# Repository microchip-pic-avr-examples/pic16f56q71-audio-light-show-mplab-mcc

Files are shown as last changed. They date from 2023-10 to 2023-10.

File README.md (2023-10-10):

MCHP (https://www.microchip.com)

# Audio Light Show Using PIC18-Q71

This project shows the functionality behind a real-time audio processing light show built extremely efficiently on a PIC18-Q71 microcontroller (MCU). 90% of the functionality runs on the MCU without engaging the CPU through the use of various Core-Independent Peripherals (CIPs).

The PIC18-Q71 on-chip analog, consisting of the Operational Amplifier ([OPA](https://www.microchip.com/en-us/products/microcontrollers-and-microprocessors/8-bit-mcus/core-independent-and-analog-peripherals/integrated-analog/operational-amplif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)) and Analog-to-Digital Converter ([ADC](https://www.microchip.com/en-us/products/microcontrollers-and-microprocessors/8-bit-mcus/core-independent-and-analog-peripherals/integrated-analog/analog-to-digital-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)) modules, measure the incoming analog frequencies and use Direct Memory Access ([DMA](https://www.microchip.com/en-us/products/microcontrollers-and-microprocessors/8-bit-mcus/core-independent-and-analog-peripherals/system-flexibility/direct-memory-acc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)) to transfer the readings into the Universal Asynchronous Receiver and Transmitter ([UART](https://www.microchip.com/en-us/products/microcontrollers-and-microprocessors/8-bit-mcus/core-independent-and-analog-peripherals/communication-connectivity-periphera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))/[DMX512](https://www.microchip.com/en-us/products/microcontrollers-and-microprocessors/8-bit-mcus/core-independent-and-analog-peripherals/communication-connectivity-periphera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) module to transmit to the receivers. Each receiver also uses a PIC18-Q71 to receive the DMX data and then appropriately drives WS2812 LEDs through its Serial Peripherals Interface ([SPI](https://www.microchip.com/en-us/products/microcontrollers-and-microprocessors/8-bit-mcus/core-independent-and-analog-peripherals/communication-connectivity-periphera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)) module. The receivers are daisy-chained through ethernet cables that transfer both data and power.

The first image below displays seven receviers responding to music, while the other one shows a standby effect. The transmitter has an AUX cable plugged in off-screen.

DMX Video 2
DMX Video 1

## Related Documentation

- [PIC18-Q71 Data Sheet](https://ww1.microchip.com/downloads/aemDocuments/documents/MCU08/ProductDocuments/DataSheets/PIC18F26-46-56Q71-Microcontroller-Data-Sheet-DS40002329.pdf)
- [TB3204 - DMX-512 using the UART with Protocol Support](https://ww1.microchip.com/downloads/en/Appnotes/TB3204-DMX-512-using-UART-90003204A.pdf) - Setting up DMX with DMA on a PIC18
- [PIC18F56Q71 Curiosity Nano Hardware User Guide](https://ww1.microchip.com/downloads/aemDocuments/documents/MCU08/ProductDocuments/UserGuides/PIC18F56Q71-CuriosityNano-HW-UG-DS50003481.pdf) - Development tools documentation
- [MIC28517 Data Sheet](https://ww1.microchip.com/downloads/aemDocuments/documents/APID/ProductDocuments/DataSheets/MIC28517-Data-Sheet-DS20006317C.pdf) - Voltage Converter Data Sheet 

## Software Used

- [MPLAB® X IDE 6.1.5](https://www.microchip.com/en-us/development-tools-tools-and-software/mplab-x-ide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) or newer
- [MPLAB XC8 2.45.0](https://www.microchip.com/en-us/development-tools-tools-and-software/mplab-xc-compilers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) or newer
- [MPLAB Code Configurator (MCC) 3.95.0](https://www.microchip.com/mplab/mplab-code-configurator) or newer

## Setup

To operate the demo, connect all the transmitters and receivers with an Ethernet cable. Power up the transmitter with a 48V power supply and connect an AUX cable to watch the incoming audio signal come to life. Each receiver is selectively listening to specific DMX data. A DIP switch on each receiver dictates what incoming DMX data to listen to, effectively defining a node number.

Apart from the final transmitter and receiver boards shown in the initial image representations, 3D printed stands are also shown which are used to mount the receiver boards and the diffusing tubes. The diffusing tubes consist of WS2812 LEDs taped to an aluminum strip for support. Inside the fluorescent tube guard, parchment paper lines the interiors and a 3D printed cap securely holds the aluminum strip towards the back of the tube ensuring optimal LED diffusion.

## Theory of Operation

This demo can be broken up into three portions:
* [Audio Signal Processing](#audio-signal-processing)
* [DMX Data](#dmx-data)
* [Driving the WS2812 LEDs](#driving-the-ws2812-leds)

The distinguishing feature of this project is nearly all of this demo operates without the CPU, and instead using CIPs and the DMA. The CPU's sole task is to run the manually programmed visual effects that convert the acquired frequency data into LED data.

### Audio Signal Processing
To obtain the initial audio data, this project extracts bins of audio frequencies and performs peak detection on each bin giving a value corresponding to the intensity of the audio frequency. Each peak is then visually represented on a different LED tube.

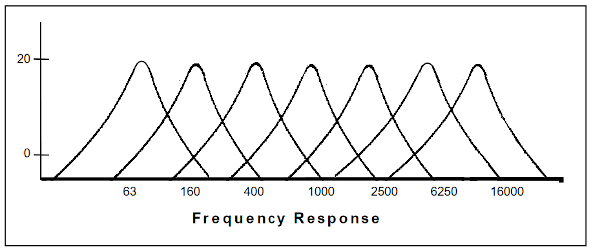
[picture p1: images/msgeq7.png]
Frequency peaks


Source: [MSGEQ7 data sheet](https://www.sparkfun.com/datasheets/Components/General/MSGEQ7.pdf)

To extract and acquire these audio frequency bins, analog bandpass filters with an ADC can be used for each desired frequency. Alternatively, an MSGEQ7 chip was used to reduce the number of needed passive components. This chip functions as a bandpass filter, multiplexing between frequencies. The PIC18-Q71 drives the chip to change where the center frequency is and then uses its on-board ADC to sample the peak. The PIC18-Q71's OPA is used in Unity Gain mode to impedance match the output, then the ADC with computation is used to acquire the output peak.

By using the OPA in Unity Gain mode, a buffer is created that ensures the ADC can read the analog signal without affecting it. If the input from the filters is of high impedance, the ADC may not read the result accurately. By using the OPA as a buffer, this ensures the ADC can always read the signal accurately and without affecting the original signal. Also, the ADC has built-in computation that provides an automatic average of readings to eliminate potential outliers, providing a more accurate reading.

### DMX Data
DMX512, or DMX for short, is an industry-standard protocol commonly used to control stage lighting and theatrical effects, providing centralized control of multiple devices from a single controller. Devices in a DMX network are daisy-chained together creating a "DMX universe". Within each universe, each node listens to the start code and specific data bytes out of the 512 bytes in each packet.

DMX Universe

For this DMX light show, each node listens to 3 bytes and the start code. Depending on the start code, the nodes interpret their three bytes differently, giving DMX flexibility on the fly.

DMX Reactive

| Start Code | Mode | Byte 1 | Byte 2 | Byte 3 |
| ---- | ---- | ---- | ---- | ---- |
| 2 | Reactive | G LED Data  | R LED Data | B LED Data |
| 3 | Visualizer | # of LEDs to Turn On | Color Change Threshold 1 | Color Change Threshold 2 |

 When `Start Code = 2`, each byte represents the entire tube's RGB data. For the first receiver, when `Start Code = 2` and the data are as shown above (`G = 255, R = 0, B = 0`), the tube looks like in the left image. When `Start Code = 3`, the data interpretation is altered to the table below and the tube for receiver 1 changes to what is shown in the image on the right.
 
DMX Visualizer

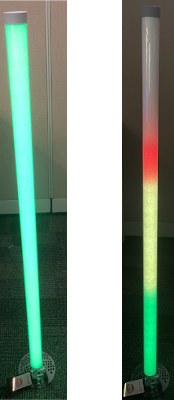
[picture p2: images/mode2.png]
Tube Shown Reactive


DMX provides the needed structure for fast and flexible data. The PIC18-Q71 compliments DMX by allowing the data's meaning to be changed based on Input/Output (I/O). The data interpretation is changed by toggling a switch, which changes the start code.

### Driving the WS2812 LEDs
After the DMX data has been received, the WS2812 LEDs change to reflect the incoming data. WS2812 LEDs are programmable through a 1-Wire protocol. The LEDs are daisy-chained together, similar to the DMX protocol, but each LED receives all the data, strips off its portion, and sends the data onward. The data for each LED consists of one byte for G, R, and B data respectively (for a total of three bytes).

WS2812

To drive the WS2812 protocol, the microcontroller pulls a line high or low for different amounts of time:

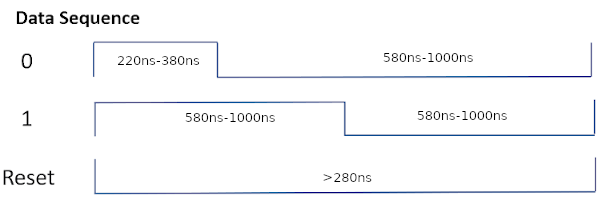
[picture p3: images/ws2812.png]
WS2812 Timing


This requires an I/O line to be changed every 220 ns or at least 4.5 million times per second requiring 4.5 Mhz of processing power. This could create a processing bottleneck in time-sensitive applications. Alternatively, the SPI module of the PIC18-Q71 device family can creatively drive the WS2812 protocol in hardware, so that the MCU simply needs to load the SPI buffer with multiple data bytes instead of individually driving each bit. This is done by chaining the SPI module with the PWM and Configurable Logic Cell (CLC) CIPs to create the serial output needed by the WS2812 protocol.

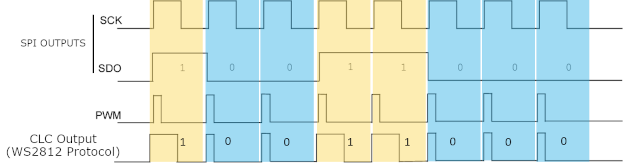
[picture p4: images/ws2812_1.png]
WS2812 1 Implementation


*SPI + PWM + CLC Waveform*

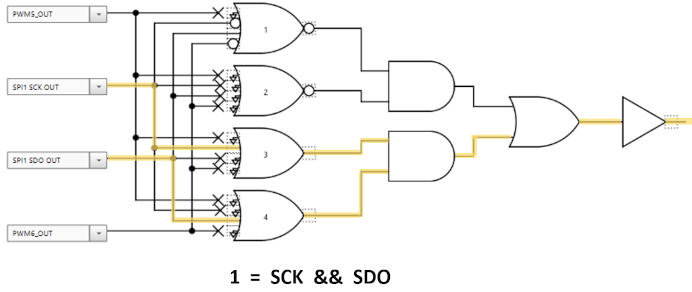
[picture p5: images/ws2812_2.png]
WS2812 2 Implementation


Implementation with CLC's - Generating 0's

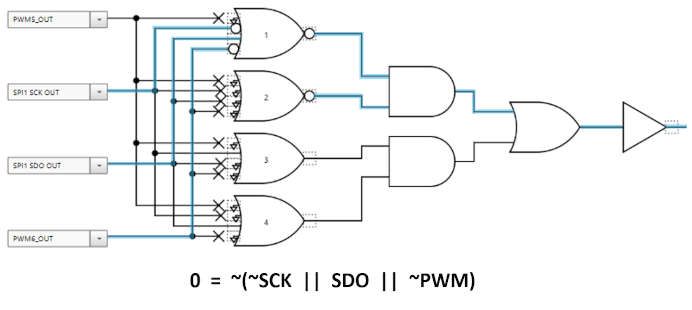
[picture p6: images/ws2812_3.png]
WS2812 3 Implementation


Implementation with CLC's - Generating 1's

## Development Hardware Used

For a large-scale project that shows many moving parts working together, it helps to first set up using easy-to-use hardware, then transition to something more polished and stable.

This project was first set up using [Curiosity Development boards](https://www.microchip.com/en-us/tools-resources/evaluation-boards/curiosity) and jumper wires. Curiosity Development boards feature an on-board programmer, meaning that only a USB cable was needed to program each PIC18-Q71. As the features were developed and the hardware requirements stopped changing, the project was transitioned to dedicated PCBs. Below is the main hardware used for the initial prototype.

- PIC18F56Q71 Curiosity Nano ([EV01G21A](https://www.microchip.com/en-us/development-tool/EV01G21A))
- Curiosity Nano Base for Click Boards™ ([AC164162](https://www.microchip.com/en-us/development-tool/ac164162))
- [MSGEQ7 Graphic Equalizer Display Filter](https://www.sparkfun.com/products/10468)
- [WS2812 LED Strip](https://www.amazon.com/BTF-LIGHTING-Waterproof-Flexible-Individually-Addressable/dp/B01CDTEEZ2/)

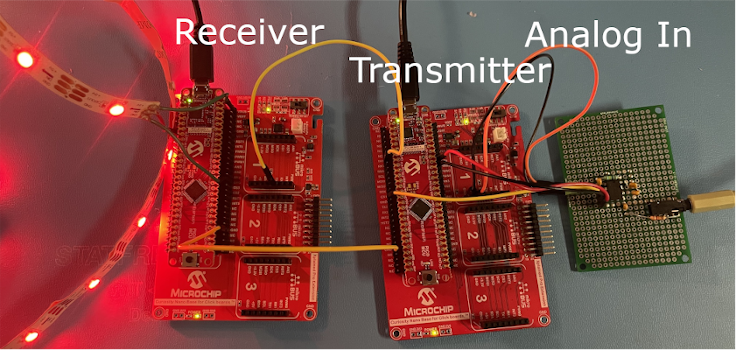
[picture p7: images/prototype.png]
Prototype Hardware


The perfboard held the supporting circuitry for the MSGEQ7 to acquire the analog signal. After the analog signal was acquired, a single-ended signal transmitted the DMX data to the receiver board which drive the WS2812 LED, as shown on the left. One other notable point is the Curiosity Nanos all needed to connect to A/C power, greatly limiting the decentralized nature of the daisy-chained DMX protocol. The PIC18F56Q71 was used since it is the family variation used on the Curiosity Nano boards, but any PIC18-Q71 can be used for the project, provided the pin output settings were changed in the code.

The final design was built on PCBs that encoded the DMX signal per the DMX specification, using RS-485 differential signaling for signal integrity of up to 4,000 feet. Also, instead of using XLR cables for the DMX signal, Ethernet cables were used, enabling Power over Ethernet (PoE) to be run through the same cable, eliminating the central power source requirement. This allows only one connection to a power source and large cable runs for the demo to be set up across a stage or even a room - perfect for traveling musicians who need to set up and tear down their equipment quickly.

## Final Hardware Used

- [MPLAB PICkit™ 5 In-Circuit Debugger](https://www.microchip.com/en-us/development-tool/pg164150)

### The Transmitter
The transmitter was built on a custom 4-layer PCB. All parts used are in the [Transmitter Bill of Materials](./PCBs/DMX%20Transmitter/dmxTxBOM.csv) in this repository, as well as all of the corresponding [files needed to have the boards manufactured](./PCBs/DMX%20Transmitter/dmxTx-Outputs.zip). Similar to the prototype hardware, the audio signal comes in and the PIC18-Q71 processes it and sends out the DMX data, but this time, it does so on an Ethernet cable. As noted above, passive PoE was implemented so a 48V power source is used and a MIC28517 buck converter steps down the voltage to the MCU's required five volts.

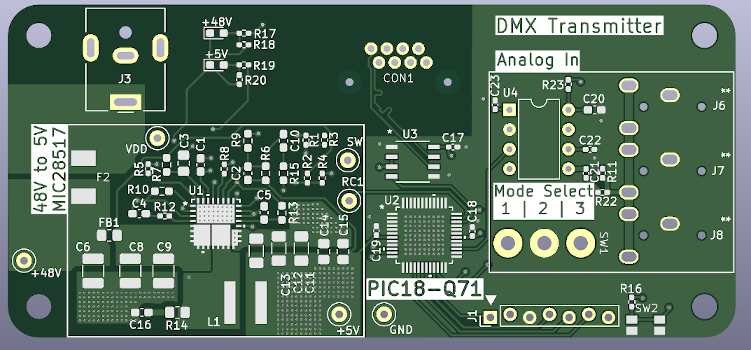
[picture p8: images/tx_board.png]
TX Board Unpopulated


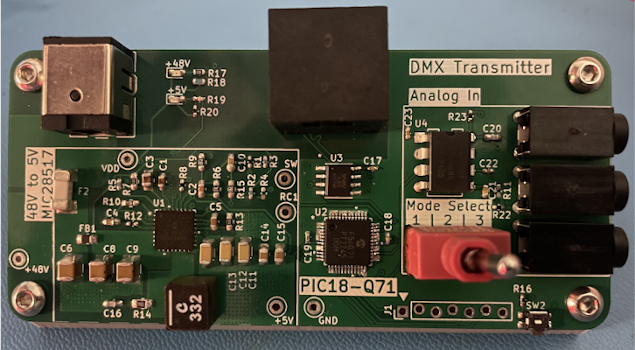
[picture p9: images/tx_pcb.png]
TX Board Populated


Notable parts in each of the section of the board:

## Analog In
 The [MSGEQ7](https://www.sparkfun.com/products/10468) extracts the amplitudes of seven frequency bands from an audio signal to be displayed.

## PIC18-Q71
The [PIC18-Q71](https://www.microchip.com/en-us/products/microcontrollers-and-microprocessors/8-bit-mcus/pic-mcus/pic18-q71) drives and reads the MSGEQ7 output by first matching the analog impedance using its on-chip OPA as a unity gain buffer, then sampling the signal using its ADC. It then sends out lighting data to each of the receiver nodes over DMX.

## 48 to 5V
The [MIC28517](https://www.microchip.com/en-us/product/mic28517) was chosen since it can handle the 48V requirements of PoE while providing up to 8A. Each receiver node needs up to 1.5A for the WS2812 LEDs, so this chip gives us plenty of overhead.

## SP485
This chip converts the outgoing DMX signal into a differential pair (RS-485) for increased signal distance (U3 on schematic).

### The Receivers
The receiver [Bill of Materials](./PCBs/DMX%20Receiver/dmxRx.csv) and [board files](./PCBs/DMX%20Receiver/dmxRx-v2Outputs.zip) are included in this repository. The receivers function the same as in the prototype, but have Ethernet connectors on either side pass through the power and DMX signals to continue the daisy chain. The PIC18-Q71 on each receiver takes the DMX data in and then appropriately drives the WS2812 LEDs using its CIPs. Each receiver is programmed using a PICkit™ 5 programmer, as opposed to the on-board PKOB programmer on the Curiosity Nanos used during development.

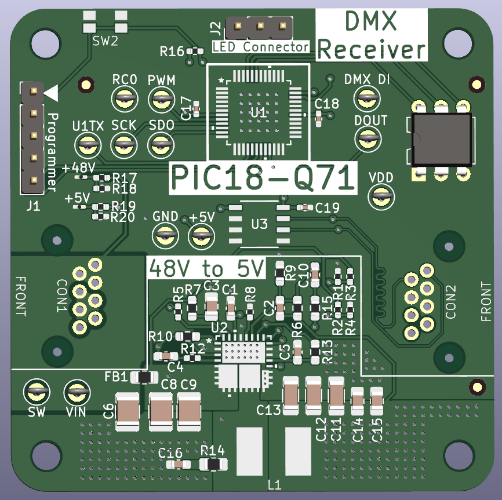
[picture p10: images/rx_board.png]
RX Board Unpopulated

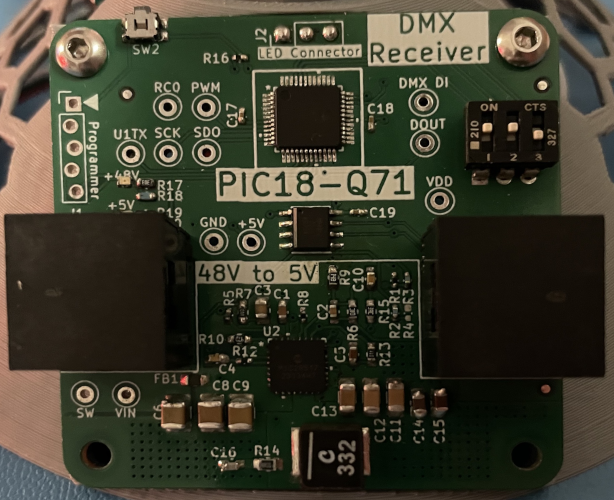
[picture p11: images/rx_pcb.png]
RX Board Populated


## Summary
This project covered the theory and functional implementation of a real-time audio light show using the PIC18-Q71. It provides the foundation for scaling this idea into a full-scale application or modifying it as needed.

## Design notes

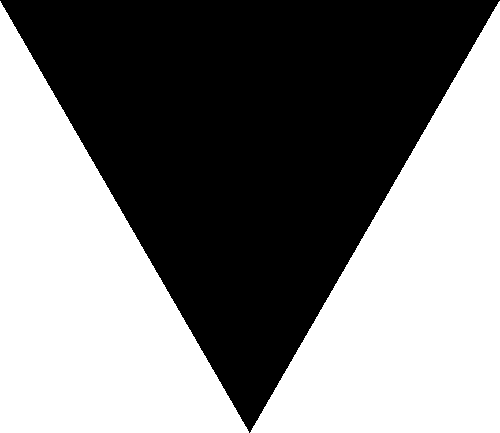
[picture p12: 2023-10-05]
PCB_Design_Files/DMX Receiver/pickit_arrow.png

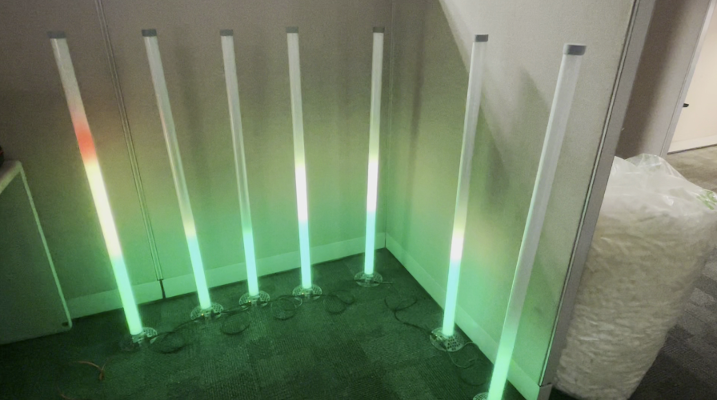
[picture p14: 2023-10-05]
images/demo_functional.png

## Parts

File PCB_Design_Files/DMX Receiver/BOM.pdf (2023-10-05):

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

https://www.digikey.com/en/products/detail/coilcraft/XGL6060-332MEC/15794210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

https://www.digikey.com/en/products/detail/yageo/AC0603FR-1010KL/13694182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

https://www.digikey.com/en/products/detail/panasonic-electronic-components/EVQ-P7A01P/4429447

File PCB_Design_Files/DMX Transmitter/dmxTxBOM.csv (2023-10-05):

Source: | C:\Users\C70636\Git Repo\dmx\PCBs\DMX Transmitter\dmxTx.kicad_sch
Date: | 8/28/2023 8:48:47 AM
Tool: | Eeschema 7.0.6
Generator: | C:\Program Files\KiCad\7.0\bin\scripting\plugins/bom_csv_grouped_by_value_with_fp.py
Component Count: | 69
Ref | Qnty | Value | Cmp name | Footprint | Description | Vendor | DNP
C1, C5 | 2 | 4.7uF | C | Capacitor_SMD:C_0603_1608Metric_Pad1.08x0.95mm_HandSolder | Unpolarized capacitor | https://www.digikey.com/en/products/detail/murata-electronics/GRM188C71A475KE11D/4905309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
C2 | 1 | 4700pF | C | Capacitor_SMD:C_0603_1608Metric_Pad1.08x0.95mm_HandSolder | Unpolarized capacitor | https://www.digikey.com/en/products/detail/kemet/C0603C472K5RACAUTO/3314891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
C3 | 1 | 1uF | C | Capacitor_SMD:C_0805_2012Metric_Pad1.18x1.45mm_HandSolder | Unpolarized capacitor | https://www.digikey.com/en/products/detail/murata-electronics/GCM21BC72A105KE36L/6606065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
C4, C10 | 2 | 0.1uF | C | Capacitor_SMD:C_0603_1608Metric_Pad1.08x0.95mm_HandSolder | Unpolarized capacitor | https://www.digikey.com/en/products/detail/w%C3%BCrth-elektronik/885012206120/11479578
C6, C8, C9 | 3 | 10uF | C | Capacitor_SMD:C_1210_3225Metric_Pad1.33x2.70mm_HandSolder | Unpolarized capacitor | https://www.digikey.com/en/products/detail/murata-electronics/GRM32EC72A106KE05L/7319245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
C11, C12, C13 | 3 | 100uF | C | Capacitor_SMD:C_1206_3216Metric_Pad1.33x1.80mm_HandSolder | Unpolarized capacitor | https://www.digikey.com/en/products/detail/samsung-electro-mechanics/CL31A107MQHNNNE/3889868
C14, C15 | 2 | 22uF | C | Capacitor_SMD:C_0805_2012Metric_Pad1.18x1.45mm_HandSolder | Unpolarized capacitor | https://www.digikey.com/en/products/detail/murata-electronics/GRM21BC81C226ME44L/4905510
C16 | 1 | 1000pF | C | Capacitor_SMD:C_0603_1608Metric_Pad1.08x0.95mm_HandSolder | Unpolarized capacitor | https://www.digikey.com/en/products/detail/w%C3%BCrth-elektronik/885012206120/11479578
C17, C18, C19, C22, C23 | 5 | 0.1u | C | Capacitor_SMD:C_0402_1005Metric_Pad0.74x0.62mm_HandSolder | Unpolarized capacitor | https://www.digikey.com/en/products/detail/samsung-electro-mechanics/CL05A104KA5NNNC/3886701
C20 | 1 | 33p | C | Capacitor_SMD:C_0603_1608Metric_Pad1.08x0.95mm_HandSolder | Unpolarized capacitor | https://www.digikey.com/en/products/detail/kemet/C0603C330K4HAC7867/7946792
C21 | 1 | 0.01u | C | Capacitor_SMD:C_0402_1005Metric_Pad0.74x0.62mm_HandSolder | Unpolarized capacitor | https://www.digikey.com/en/products/detail/samsung-electro-mechanics/CL05B103KB5NNNC/3886686
CON1 | 1 | ~ | E5J88-00LJG2-L | E5J88-00LJG2-L:E5J88-00LJG2-L |  | https://www.digikey.com/en/products/detail/pulse-electronics/E5J88-00LJG2-L/1785312
D1 | 1 | +48V | LED | LED_SMD:LED_0603_1608Metric_Pad1.05x0.95mm_HandSolder | Light emitting diode | https://www.digikey.com/en/products/detail/liteon/LTST-C191KSKT/386839
D2 | 1 | +5V | LED | LED_SMD:LED_0603_1608Metric_Pad1.05x0.95mm_HandSolder | Light emitting diode | https://www.digikey.com/en/products/detail/liteon/LTST-C190GKT/269230
F1 | 1 | High Amp | Fuse | 0679L9100-05:0679L9100-05 | Fuse | https://www.digikey.com/en/products/detail/bel-fuse-inc/0679L9100-05/5844042
F2 | 1 | Low Amp | Fuse | 0679L9100-05:0679L9100-05 | Fuse | https://www.digikey.com/en/products/detail/bel-fuse-inc/0679L1000-05/5844030
FB1 | 1 | 120R | FerriteBead | Resistor_SMD:R_0805_2012Metric_Pad1.20x1.40mm_HandSolder | Ferrite bead | https://www.digikey.com/en/products/detail/vishay-dale/ILHB0805ER121V/5168396
H1, H2, H3, H4 | 4 | MountingHole | MountingHole | MountingHole:MountingHole_3.2mm_M3 | Mounting Hole without connection | N/A
J1 | 1 | Conn_01x07_Socket | Conn_01x07_Socket | Connector_PinHeader_2.54mm:PinHeader_1x07_P2.54mm_Vertical | Generic connector, single row, 01x07, script generated | https://www.digikey.com/en/products/detail/adam-tech/PH1-07-UA/9830505
J3 | 1 | Jack-DC | Jack-DC | PJ-063AH:BarrelJack_CUI_PJ-063AH_Horizontal | DC Barrel Jack | https://www.digikey.com/en/products/detail/cui-devices/PJ-063AH/2161208?s=N4IgTCBcDaIAoCkC0AGAbAZgIIAkQF0BfIA
J6, J7, J8 | 3 | STX-3000 | STX-3000 | STX-3000_KYC |  | https://www.digikey.com/en/products/detail/kycon-inc/STX-3000/9975995?s=N4IgTCBcDaIMoBUAaBaAzABiyAugXyA
L1 | 1 | 3.3uH | L | XGL6060:XGL6060 | Inductor | https://www.digikey.com/en/products/detail/coilcraft/XGL6060-332MEC/15794210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
R1 | 1 | 300k | R | Resistor_SMD:R_0402_1005Metric_Pad0.72x0.64mm_HandSolder | Resistor | https://www.digikey.com/en/products/detail/panasonic-electronic-components/ERJ-2RKF3003X/1746185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
R2, R3, R5 | 3 | 100k | R | Resistor_SMD:R_0402_1005Metric_Pad0.72x0.64mm_HandSolder | Resistor | https://www.digikey.com/en/products/detail/koa-speer-electronics-inc/RK73H1ETTP1003F/9844156
R4 | 1 | 0R | R | Resistor_SMD:R_0402_1005Metric_Pad0.72x0.64mm_HandSolder | Resistor | https://www.digikey.com/en/products/detail/koa-speer-electronics-inc/RK73H1ETTP1003F/9844156 | DNP
R6 | 1 | 10k | R | Resistor_SMD:R_0603_1608Metric_Pad0.98x0.95mm_HandSolder | Resistor | https://www.digikey.com/en/products/detail/yageo/AC0603FR-1010KL/13694182
R7, R13 | 2 | 1R | R | Resistor_SMD:R_0603_1608Metric_Pad0.98x0.95mm_HandSolder | Resistor | https://www.digikey.com/en/products/detail/stackpole-electronics-inc/RNCP0603FTD1R00/2240072
R8, R12 | 2 | 0R | R | Resistor_SMD:R_0402_1005Metric_Pad0.72x0.64mm_HandSolder | Resistor | https://www.digikey.com/en/products/detail/panasonic-electronic-components/ERJ-2GE0R00X/146727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
R9 | 1 | 1.37k | R | Resistor_SMD:R_0603_1608Metric_Pad0.98x0.95mm_HandSolder | Resistor | https://www.digikey.com/en/products/detail/yageo/RC0603FR-071K37L/726860
R10 | 1 | 3.01k | R | Resistor_SMD:R_0603_1608Metric_Pad0.98x0.95mm_HandSolder | Resistor | https://www.digikey.com/en/products/detail/yageo/RC0603FR-073K01L/727121
R14 | 1 | 1R | R | Resistor_SMD:R_0805_2012Metric_Pad1.20x1.40mm_HandSolder | Resistor | https://www.digikey.com/en/products/detail/stackpole-electronics-inc/RMCF0805FT1R00/1760547
R15 | 1 | 24.9k | R | Resistor_SMD:R_0603_1608Metric_Pad0.98x0.95mm_HandSolder | Resistor | https://www.digikey.com/en/products/detail/yageo/RC0603FR-0724K9L/727080
R16 | 1 | 10k | R | Resistor_SMD:R_0402_1005Metric_Pad0.72x0.64mm_HandSolder | Resistor | https://www.digikey.com/en/products/detail/yageo/AC0402FR-0710KL/5895030
R17, R19 | 2 | 1k | R | Resistor_SMD:R_0402_1005Metric_Pad0.72x0.64mm_HandSolder | Resistor | https://www.digikey.com/en/products/detail/susumu/RR0510P-102-D/432398
R18 | 1 | 47 | R | Resistor_SMD:R_0402_1005Metric_Pad0.72x0.64mm_HandSolder | Resistor | https://www.digikey.com/en/products/detail/yageo/RC0402FR-0747RL/2827566
R20 | 1 | 790 | R | Resistor_SMD:R_0402_1005Metric_Pad0.72x0.64mm_HandSolder | Resistor | https://www.digikey.com/en/products/detail/yageo/RC0402FR-07787RL/5281093
R22 | 1 | 22k | R | Resistor_SMD:R_0402_1005Metric_Pad0.72x0.64mm_HandSolder | Resistor | https://www.digikey.com/en/products/detail/panasonic-electronic-components/ERA-2AEB223X/1706037
R23 | 1 | 200k | R | Resistor_SMD:R_0402_1005Metric_Pad0.72x0.64mm_HandSolder | Resistor | https://www.digikey.com/en/products/detail/yageo/RT0402BRD07200KL/5926115
SW1 | 1 | SW_SPDT_MSM | SW_SPDT_MSM | 100AWDP1T2B4M2QE:100AWDP1T2B4M2QE | Switch, single pole double throw, center OFF position | https://www.digikey.com/en/products/detail/e-switch/100AWSP1T2B4M2QE/1803039
SW2 | 1 | MCLR_SW | SW_Push | EVQ-P7A01P:EVQ-P7A01P | Push button switch, generic, two pins | https://www.digikey.com/en/products/detail/panasonic-electronic-components/EVQ-P7A01P/4429447
TP3 | 1 | RC1 | TestPoint | TestPoint:TestPoint_Loop_D2.50mm_Drill1.0mm | test point | N/A
TP5 | 1 | +48V | TestPoint | TestPoint:TestPoint_Loop_D2.50mm_Drill1.0mm | test point | N/A
TP9 | 1 | +5V | TestPoint | TestPoint:TestPoint_Loop_D2.50mm_Drill1.0mm | test point | N/A
TP10 | 1 | GND | TestPoint | TestPoint:TestPoint_Loop_D2.50mm_Drill1.0mm | test point | N/A
U1 | 1 | MIC28517T-E/PHA | MIC28517T-E_PHA | VQFN32_6X6_3EP_PHA_MCH |  | https://www.microchip.com/en-us/product/mic28517
U2 | 1 | PIC18F56Q71-I/PT | PIC18F56Q71-I_PT | TQFP48_PT_MCH |  | https://www.digikey.com/en/products/detail/microchip-technology/PIC18F56Q71-I-PT/17631044
U3 | 1 | SP485CN-L | SP485CN-L | NSOIC-8 |  | https://www.digikey.com/en/products/detail/maxlinear-inc/SP485CN-L/2411099
U4 | 1 | MSGEQ7 | MSGEQ7 | Package_DIP:DIP-8_W7.62mm | Seven Band Graphic Equalizer, DIP-8/SOIC-8 | https://www.sparkfun.com/products/10468

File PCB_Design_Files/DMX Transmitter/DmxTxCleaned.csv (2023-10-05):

Id | Designator | Footprint | Quantity | Designation | Supplier and ref | Column1 | _1
1 | C13,C11,C8,C10 | R_1206_3216Metric | 4 | 2.2uF | https://www.digikey.com/en/products/detail/samsung-electro-mechanics/CL31B225KCHSNNE/3888796
2 | J7,J6,J8 | STX-3000_KYC | 3 | STX-3000 | https://www.digikey.com/en/products/detail/kycon-inc/STX-3000/9975995?s=N4IgTCBcDaIMoBUAaBaAzABiyAugXyA
3 | C3 | R_0603_1608Metric | 1 | 4.7n | https://www.digikey.com/en/products/detail/tdk-corporation/CGA3E2C0G1H472J080AA/2672805
4 | L1 | 7447709006 | 1 | 6.8u | https://www.digikey.com/en/products/detail/w%C3%BCrth-elektronik/7447709006/1638645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
5 | H4,H3,H1,H2 | MountingHole_3.2mm_M3 | 4 | MountingHole | N/A
6 | U1 | VQFN32_6X6_3EP_PHA_MCH | 1 | MIC28517T-E/PHA | https://www.microchip.com/en-us/product/mic28517
7 | R9,R7 | R_0402_1005Metric | 2 | 10k | https://www.digikey.com/en/products/detail/yageo/AC0402FR-0710KL/5895030
8 | C1,C2 | R_0402_1005Metric | 2 | 0.1uF | https://www.digikey.com/en/products/detail/murata-electronics/GRM155R62A104KE14D/5027543
9 | C15,C16 | C_0402_1005Metric | 2 | 0.1u | https://www.digikey.com/en/products/detail/murata-electronics/GRM155R62A104KE14D/5027543
10 | R15 | R_0402_1005Metric | 1 | 790 | https://www.digikey.com/en/products/detail/yageo/RC0402FR-07787RL/5281093
11 | C5,C6 | R_0402_1005Metric | 2 | 47u | https://www.digikey.com/en/products/detail/murata-electronics/GRM21BR61A476ME15K/4905528
12 | U4 | DIP-8_W7.62mm | 1 | MSGEQ7 | https://www.sparkfun.com/products/10468
13 | C7,C14,C4 | R_0402_1005Metric | 3 | .1uF | https://www.digikey.com/en/products/detail/samsung-electro-mechanics/CL05B104KA5NNNC/5961204
14 | D2 | LED_0603_1608Metric | 1 | +5V | N/A
15 | R4 | R_0402_1005Metric | 1 | 25k | https://www.digikey.com/en/products/detail/vishay-dale-thin-film/PNM0402E2502BST1/4341871
16 | C12 | R_0805_2012Metric | 1 | 4.7uF | https://www.digikey.com/en/products/detail/tdk-corporation/C2012X5R2A475K125AC/14642033
17 | R10,R11 | R_0402_1005Metric | 2 | 2.2R | https://www.digikey.com/en/products/detail/yageo/RC0402FR-072R2L/1037048
18 | R8 | R_0402_1005Metric | 1 | 1.37k | https://www.digikey.com/en/products/detail/yageo/RC0402FR-071K37L/5280895
19 | R6 | R_0402_1005Metric | 1 | 2.21k | https://www.digikey.com/en/products/detail/yageo/RC0402FR-072K21L/726554
20 | J1 | PinHeader_1x05_P2.54mm_Vertical | 1 | Conn_01x05_Socket | https://www.digikey.com/en/products/detail/w%C3%BCrth-elektronik/61300511121/4846831
21 | B1 | gnd_bridge | 1 | ~ | N/A
22 | C17 | C_0402_1005Metric | 1 | 33p | https://www.digikey.com/en/products/detail/samsung-electro-mechanics/CL05C330JB5NNNC/3886930
23 | R3 | R_0402_1005Metric | 1 | 100k | https://www.digikey.com/en/products/detail/susumu/RR0510P-104-D/432443
24 | R1,R5,R2 | R_0402_1005Metric | 3 | 200k | https://www.digikey.com/en/products/detail/yageo/RT0402BRD07200KL/5926115
25 | SW1 | 100AWDP1T2B4M2QE | 1 | SW_SPDT_MSM | https://www.digikey.com/en/products/detail/e-switch/100AWSP1T2B4M2QE/1803039
26 | J3 | BarrelJack_CUI_PJ-063AH_Horizontal | 1 | Jack-DC | https://www.digikey.com/en/products/detail/cui-devices/PJ-063AH/2161208?s=N4IgTCBcDaIAoCkC0AGAbAZgIIAkQF0BfIA
27 | R13 | R_0402_1005Metric | 1 | 47 | https://www.digikey.com/en/products/detail/yageo/RC0402FR-0747RL/2827566
28 | R16 | R_0402_1005Metric | 1 | 22k | https://www.digikey.com/en/products/detail/panasonic-electronic-components/ERA-2AEB223X/1706037
29 | C18 | C_0402_1005Metric | 1 | 0.01u | https://www.digikey.com/en/products/detail/kyocera-avx/KGM05AR71E103KH/563223
30 | U2 | TQFP48_PT_MCH | 1 | PIC18F56Q71-I/PT | https://www.microchip.com/en-us/product/pic18f56q71
31 | CON1 | E5J88-00LJG2-L | 1 | ~ | https://www.digikey.com/en/products/detail/pulse-electronics/E5J88-00LJG2-L/1785312
32 | R14,R12 | R_0402_1005Metric | 2 | 1k | https://www.digikey.com/en/products/detail/susumu/RR0510P-102-D/432398
33 | D1 | LED_0603_1608Metric | 1 | +48V | https://www.digikey.com/en/products/detail/liteon/LTST-C191KSKT/386839
34 | U3 | NSOIC-8 | 1 | SP485CN-L | https://www.digikey.com/en/products/detail/maxlinear-inc/SP485CN-L/2411099
35 | C9 | R_1206_3216Metric | 1 | 1uF | https://www.digikey.com/en/products/detail/samsung-electro-mechanics/CL31B105KCHSNNE/3888405
36 | TP10 | TestPoint_Pad_D1.0mm | 1 | GND | N/A
37 | F1 | 0679L9100-05 | 1 | Fuse | https://www.digikey.com/en/products/detail/bel-fuse-inc/0679L9100-05/5844042
38 | TP9 | TestPoint_Pad_D1.0mm | 1 | +5V | N/A
39 | TP2 | TestPoint_Pad_D1.0mm | 1 | RB0 | N/A
40 | TP5 | TestPoint_Pad_D1.0mm | 1 | +48V | N/A
41 | TP3 | TestPoint_Pad_D1.0mm | 1 | RC1 | N/A
42 | TP1 | TestPoint_Pad_D1.0mm | 1 | DMX DO | N/A
43 | TP4 | TestPoint_Pad_D1.0mm | 1 | U1TX | N/A
44 | SW2 | EVQ-P7A01P | 1 | MCLR_SW | https://www.digikey.com/en/products/detail/panasonic-electronic-components/EVQ-P7A01P/4429447

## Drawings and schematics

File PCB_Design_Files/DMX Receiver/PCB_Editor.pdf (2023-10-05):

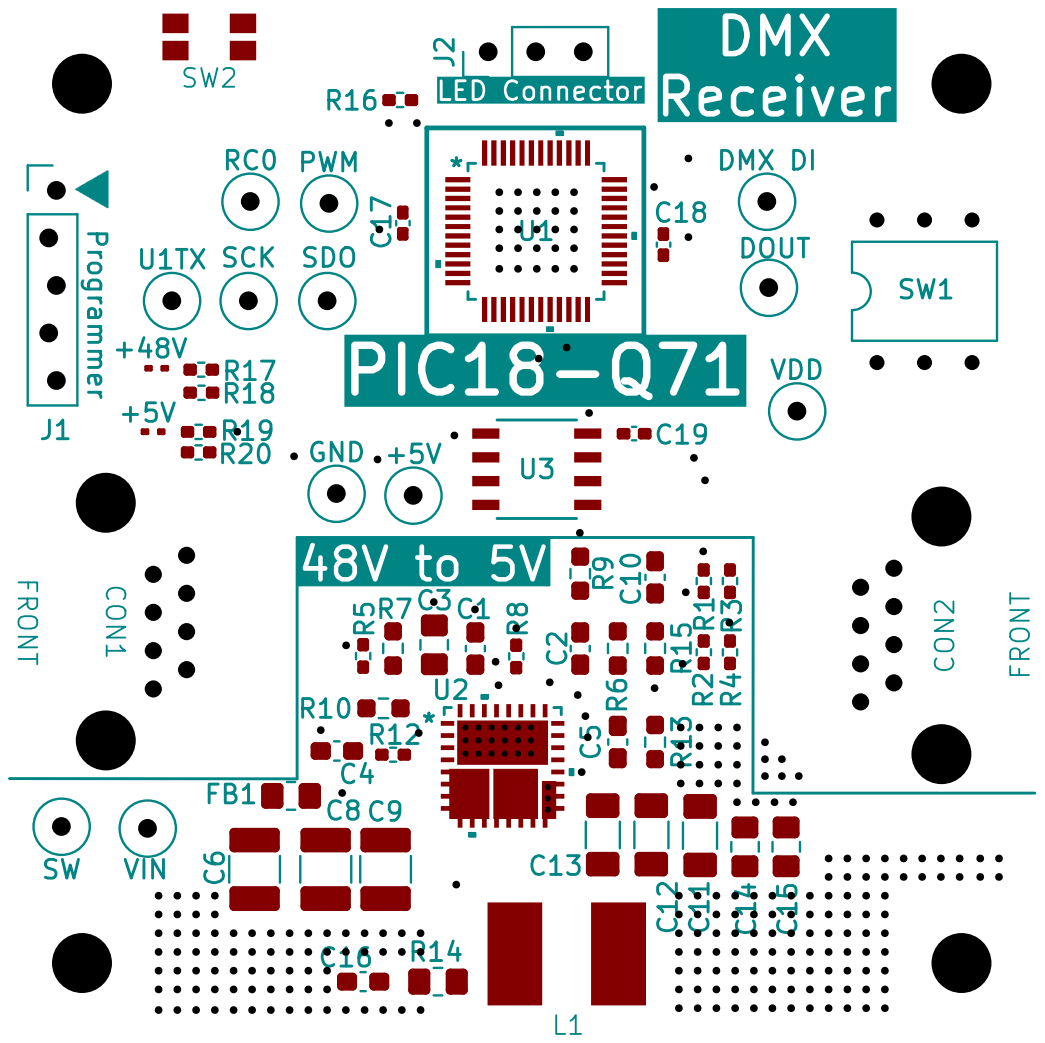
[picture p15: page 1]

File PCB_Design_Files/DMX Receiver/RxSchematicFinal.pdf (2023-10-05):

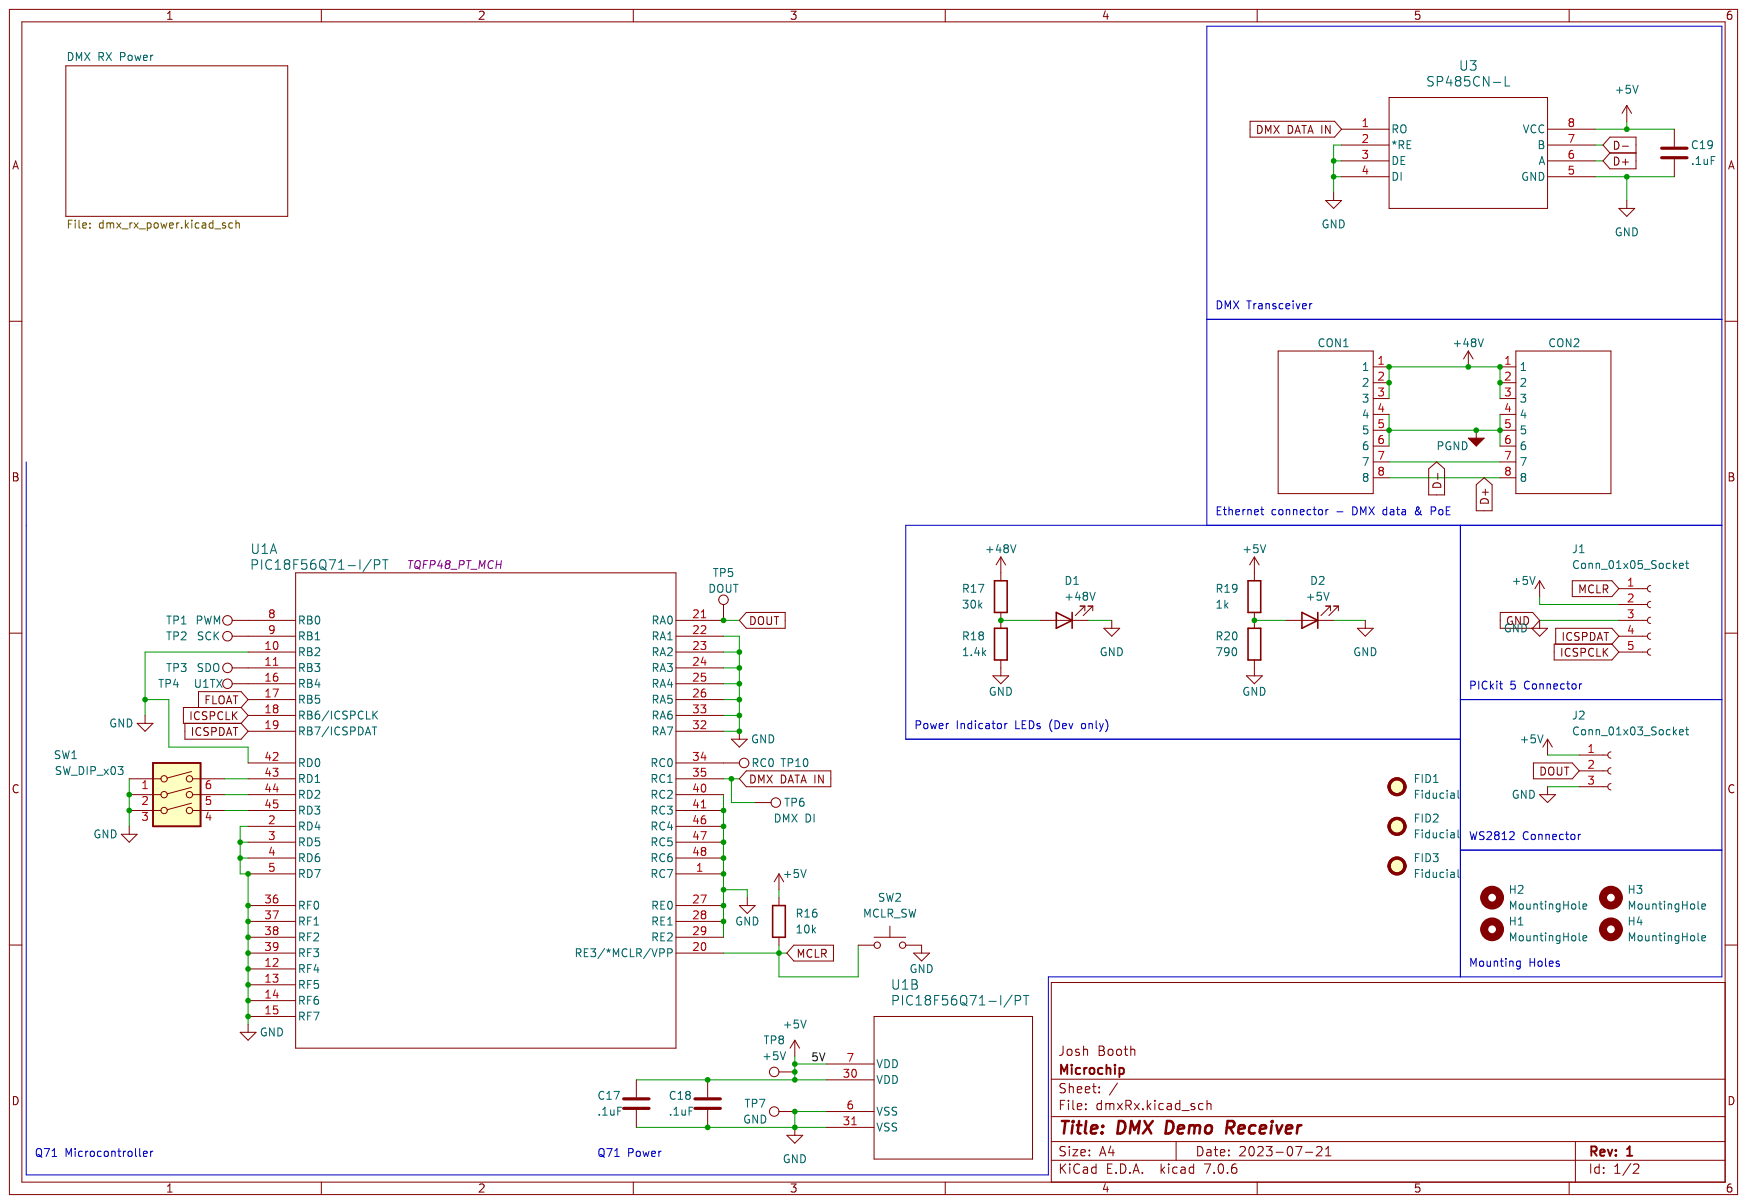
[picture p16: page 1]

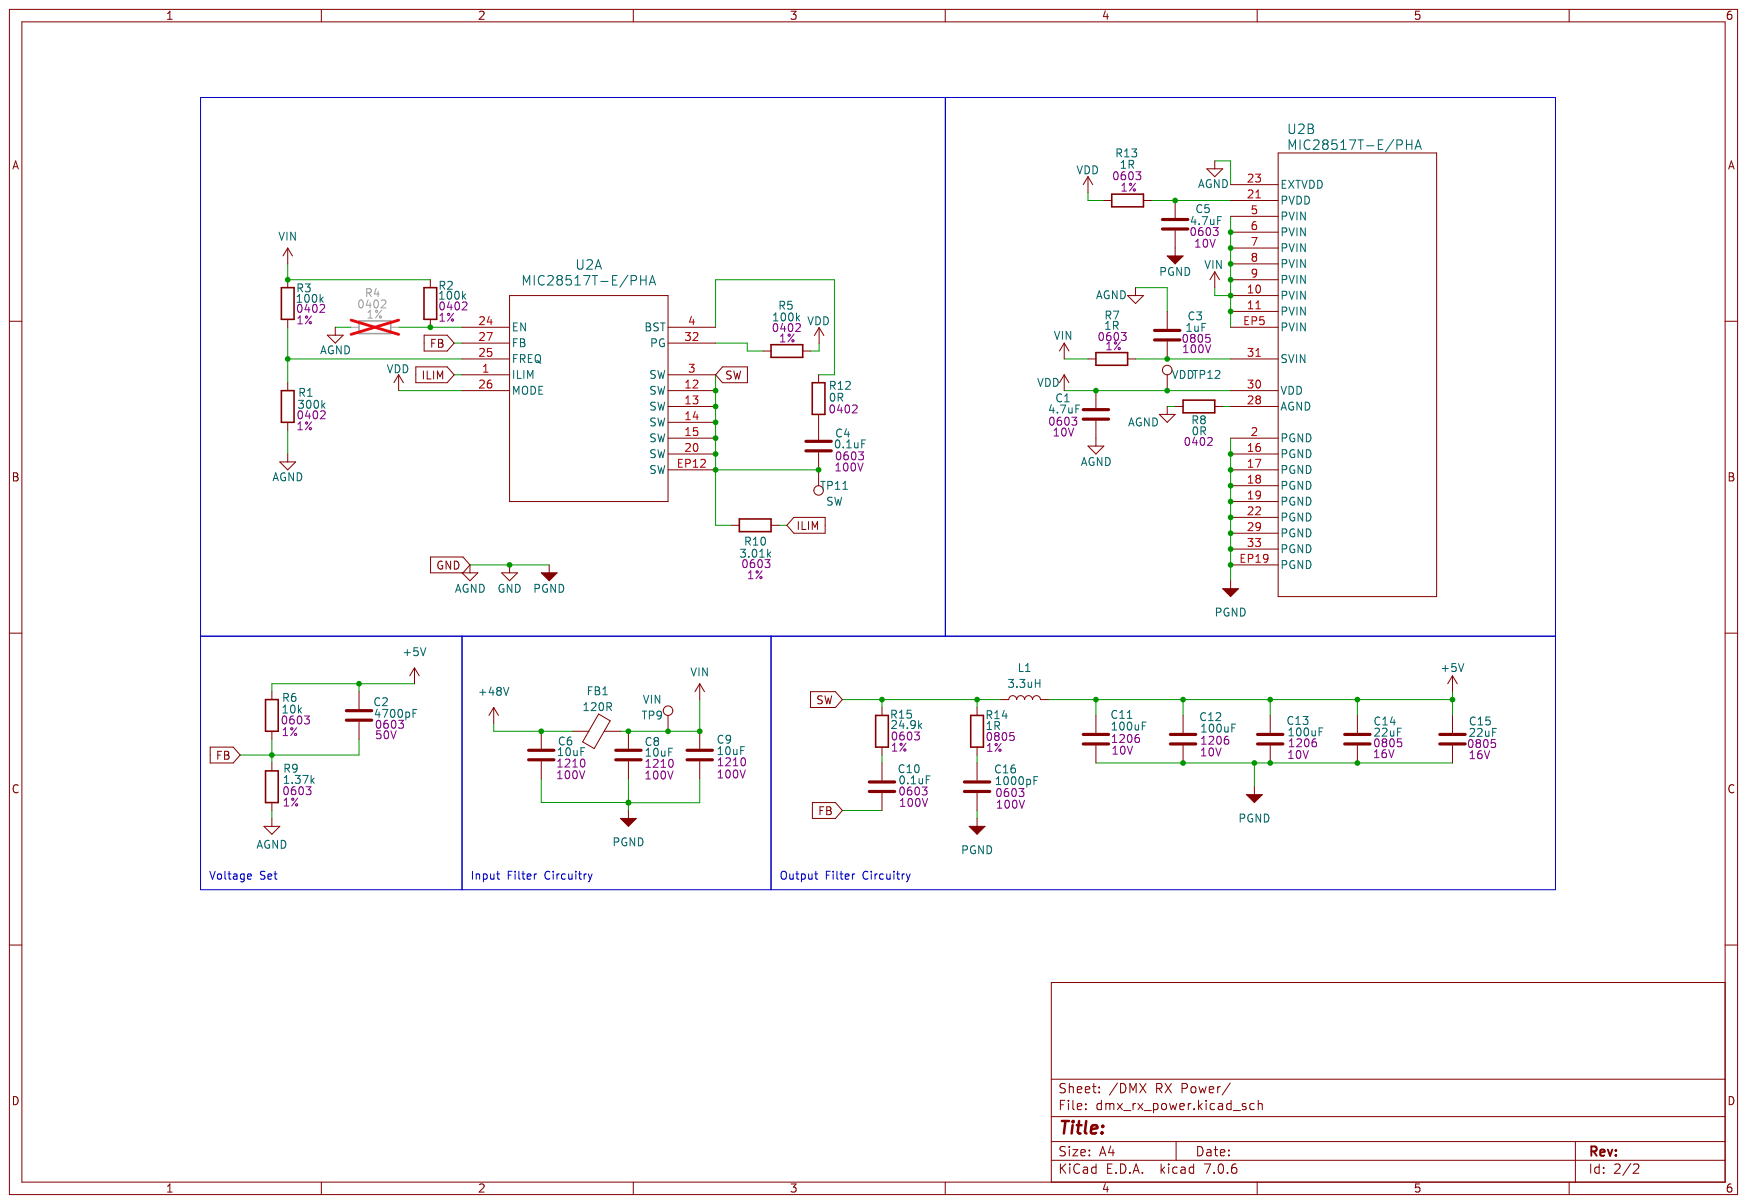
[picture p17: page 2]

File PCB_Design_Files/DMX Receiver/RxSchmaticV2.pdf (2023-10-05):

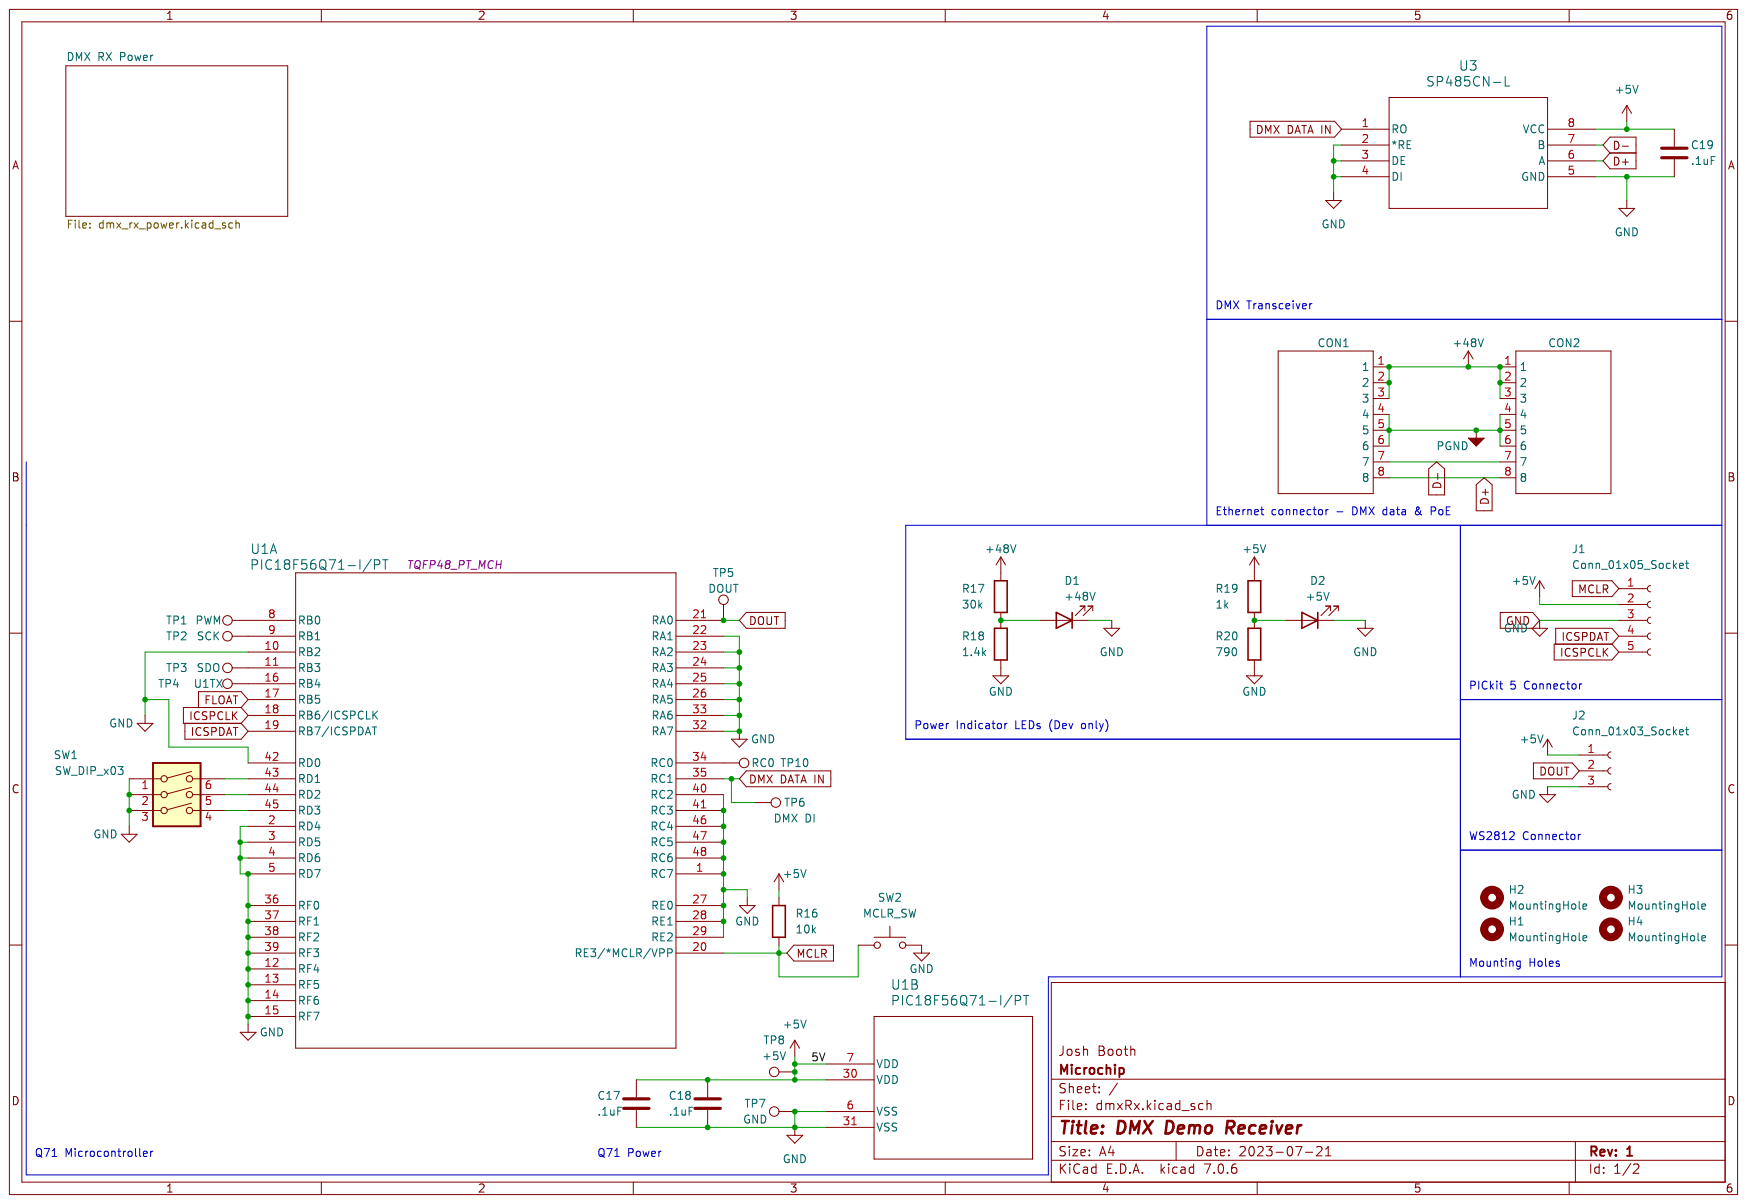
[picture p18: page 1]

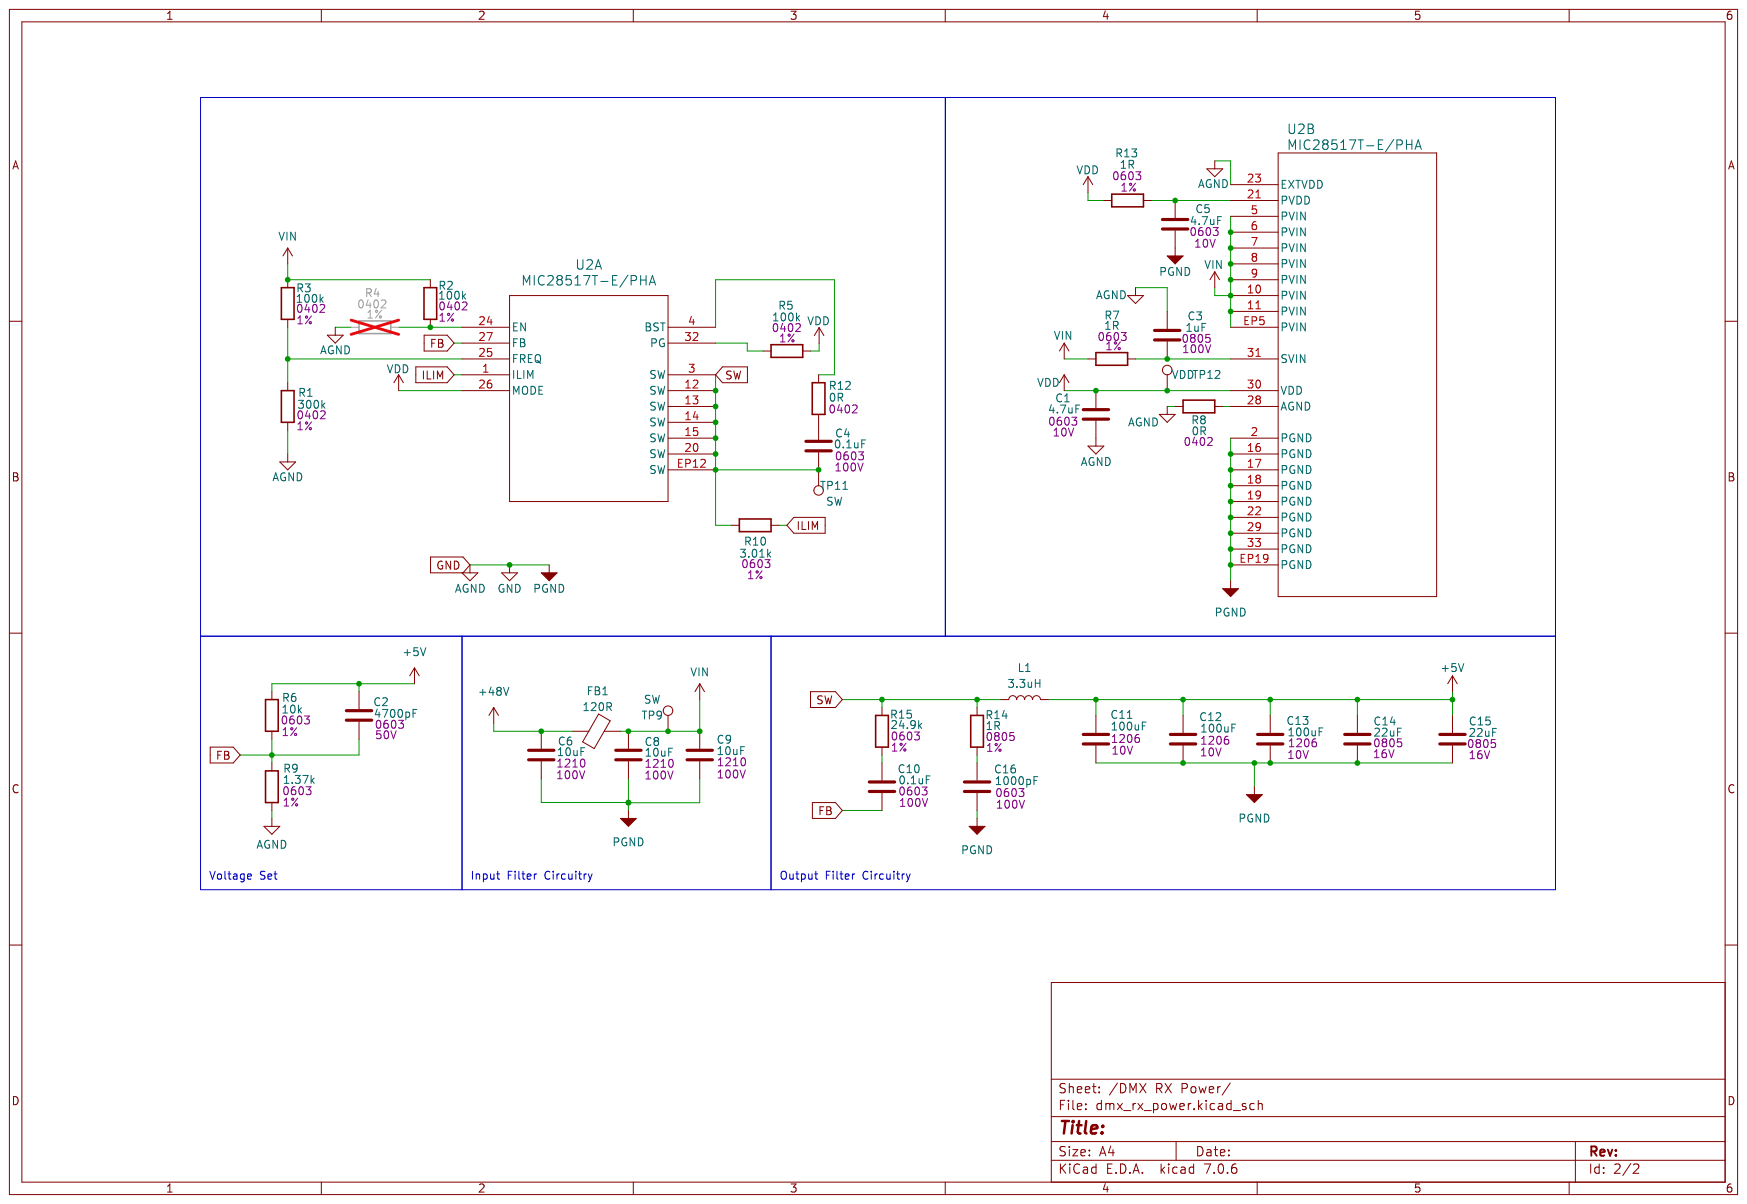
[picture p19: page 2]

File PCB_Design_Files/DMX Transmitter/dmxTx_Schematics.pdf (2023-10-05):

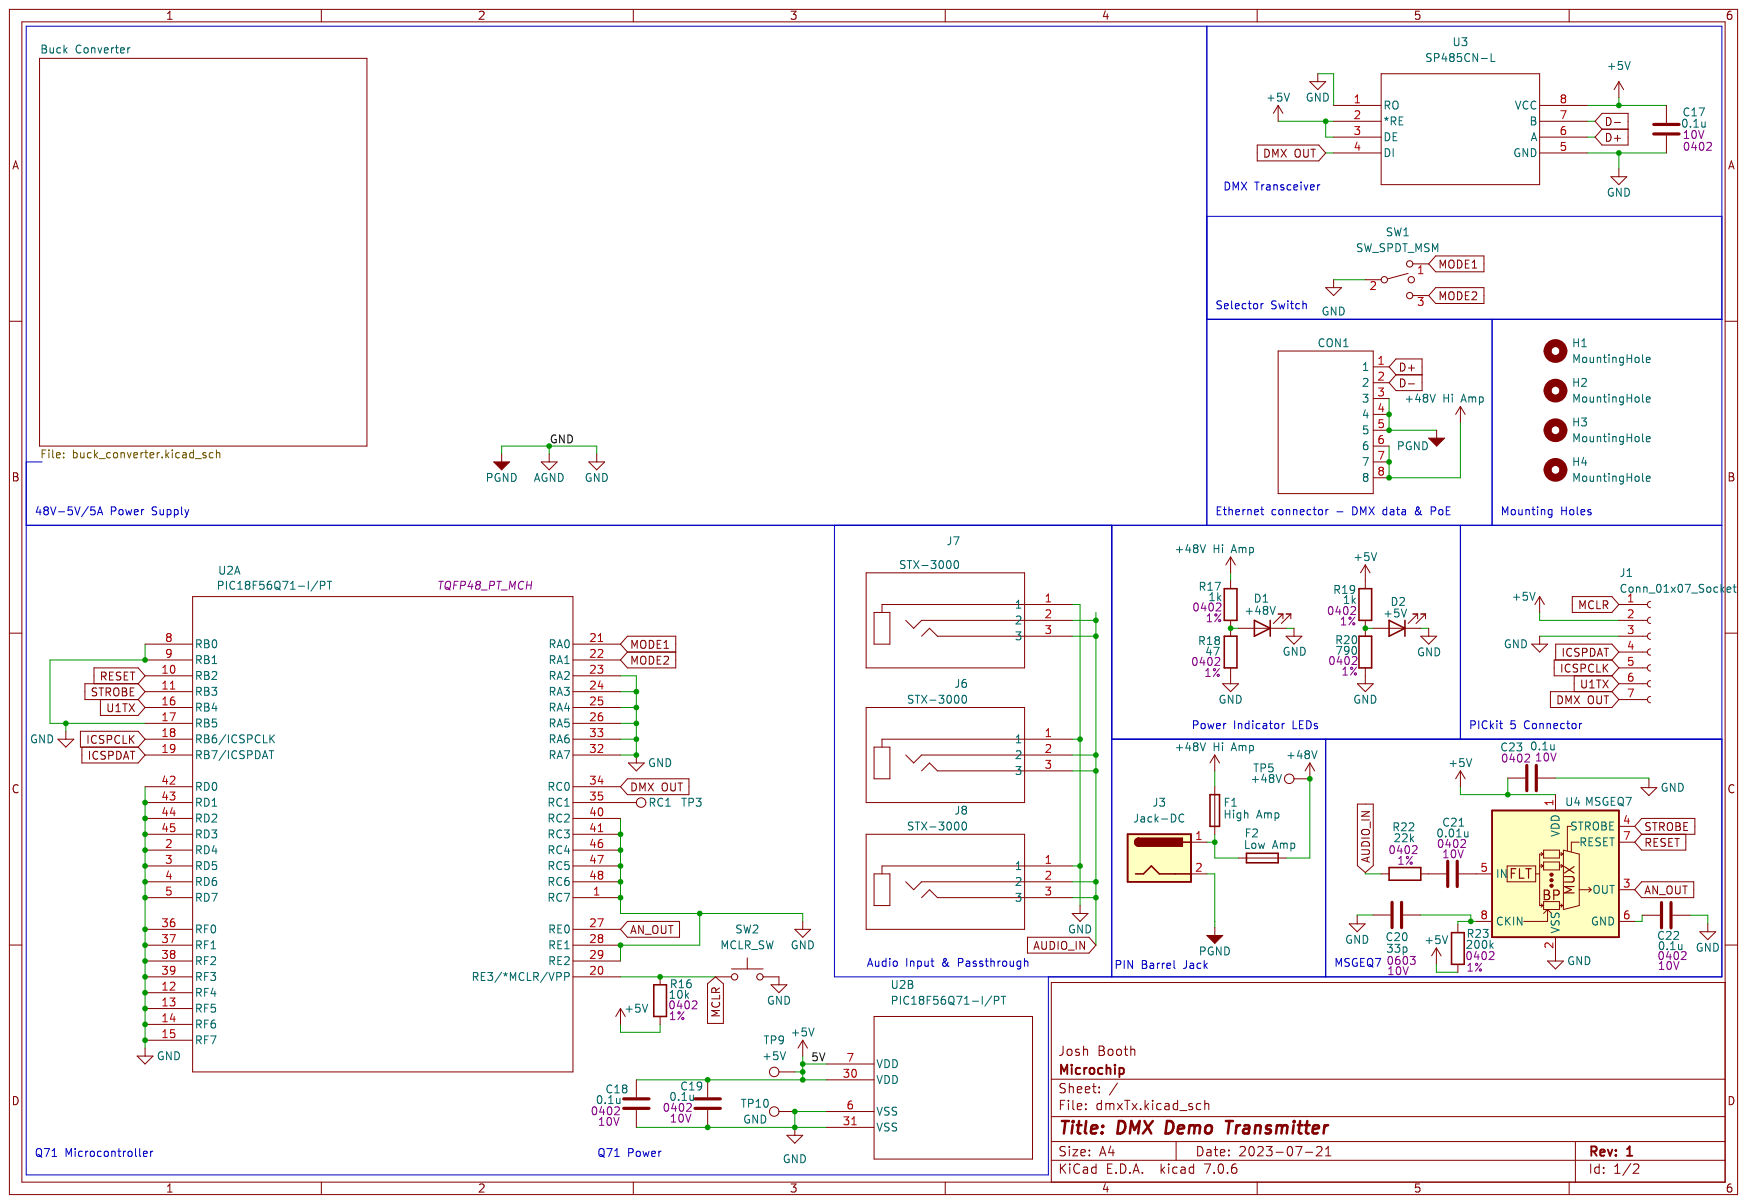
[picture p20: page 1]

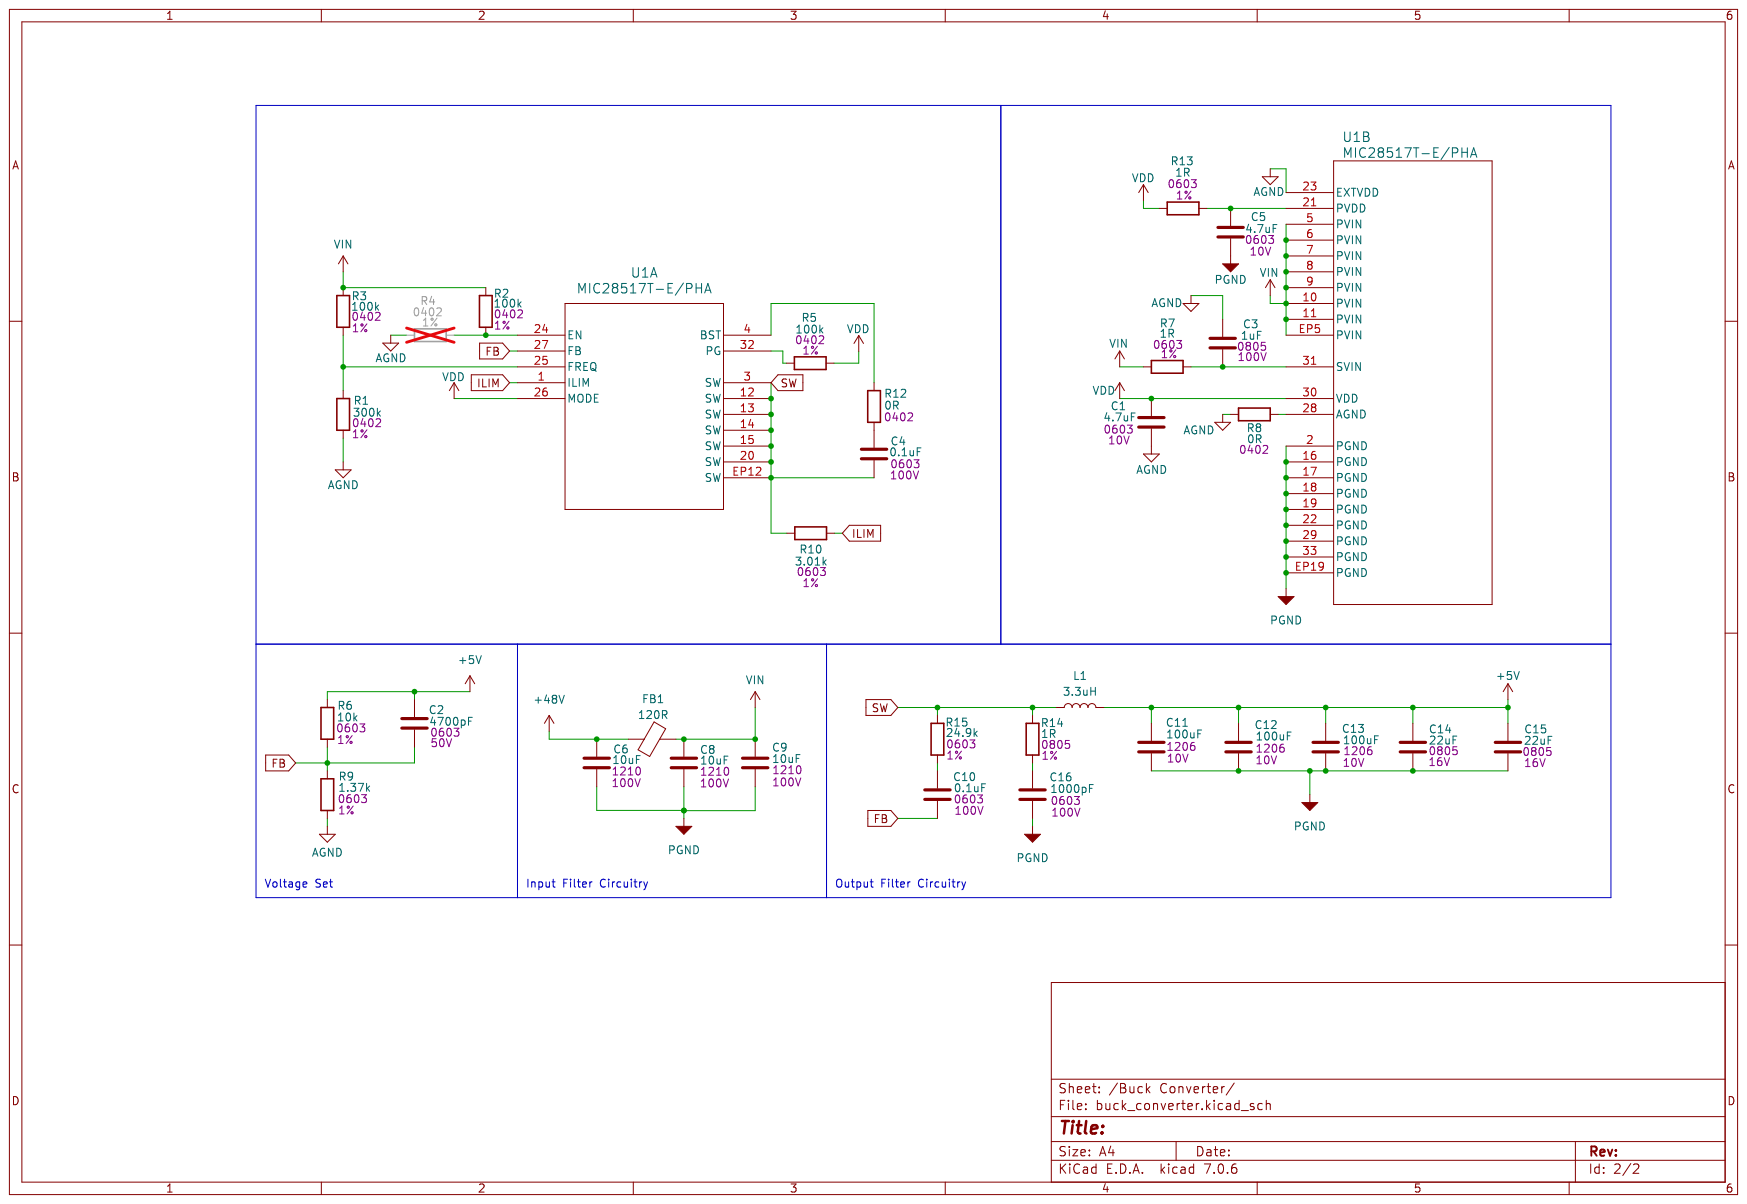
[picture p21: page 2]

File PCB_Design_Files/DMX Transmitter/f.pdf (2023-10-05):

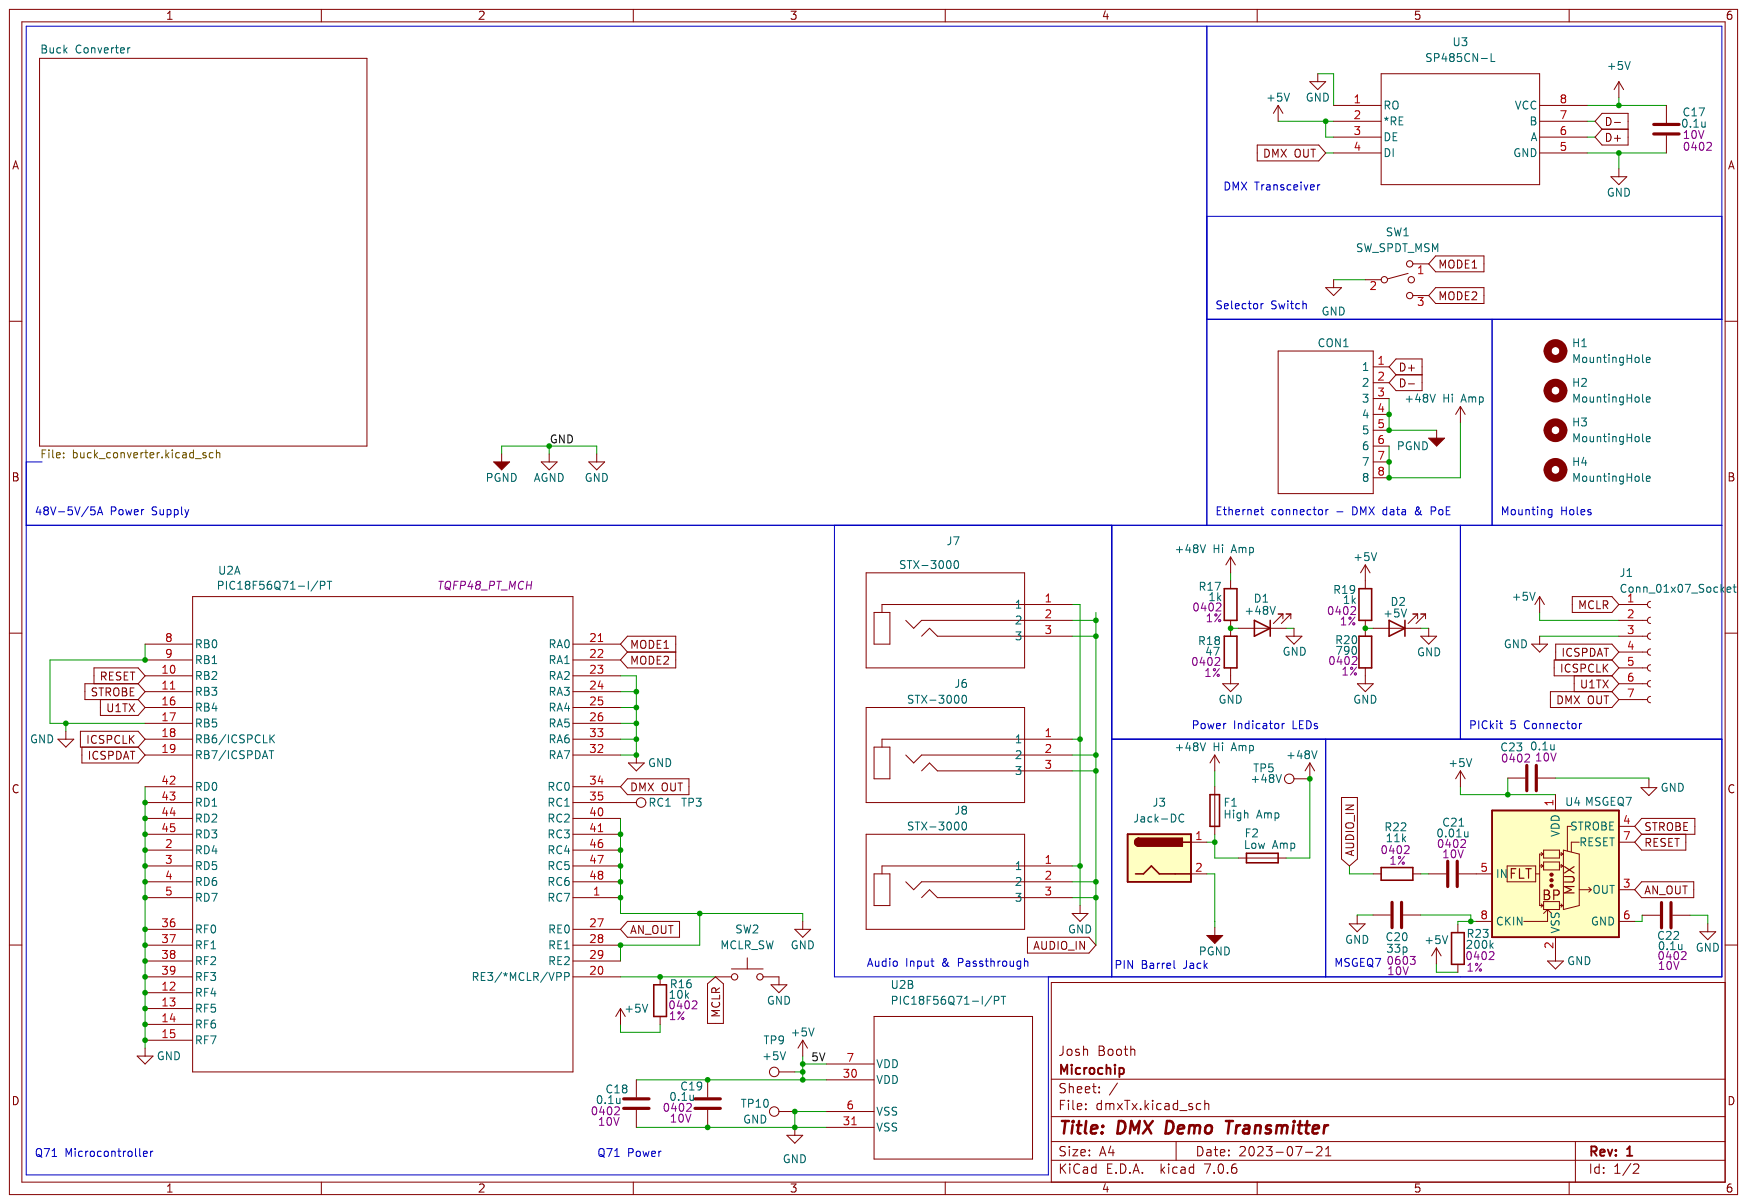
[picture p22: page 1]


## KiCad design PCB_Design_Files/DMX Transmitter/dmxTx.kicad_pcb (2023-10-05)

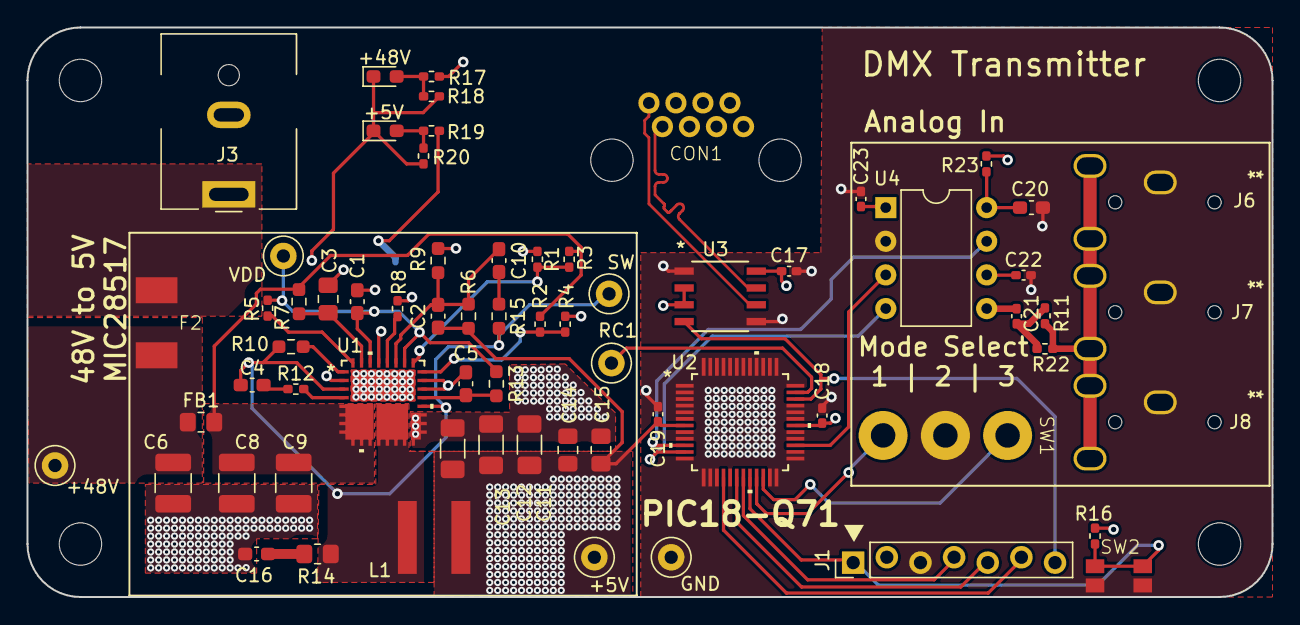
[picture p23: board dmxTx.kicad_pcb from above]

Board: 4 copper layers, 94.0 x 43.0 mm, 72 parts (1 on the bottom side), 40 nets.

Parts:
C1, C5: 4.7uF; C_0603_1608Metric_Pad1.08x0.95mm_HandSolder
C2: 4700pF; C_0603_1608Metric_Pad1.08x0.95mm_HandSolder
C3: 1uF; C_0805_2012Metric_Pad1.18x1.45mm_HandSolder
C4, C10: 0.1uF; C_0603_1608Metric_Pad1.08x0.95mm_HandSolder
C6, C8, C9: 10uF; C_1210_3225Metric_Pad1.33x2.70mm_HandSolder
C11, C12, C13: 100uF; C_1206_3216Metric_Pad1.33x1.80mm_HandSolder
C14, C15: 22uF; C_0805_2012Metric_Pad1.18x1.45mm_HandSolder
C16: 1000pF; C_0603_1608Metric_Pad1.08x0.95mm_HandSolder
C17, C18, C19, C22, C23: 0.1u; C_0402_1005Metric_Pad0.74x0.62mm_HandSolder
C20: 33p; C_0603_1608Metric_Pad1.08x0.95mm_HandSolder
C21: 0.01u; C_0402_1005Metric_Pad0.74x0.62mm_HandSolder
CON1: E5J88-00LJG2-L
D1: +48V; LED_0603_1608Metric_Pad1.05x0.95mm_HandSolder
D2: +5V; LED_0603_1608Metric_Pad1.05x0.95mm_HandSolder
F1: High Amp; 0679L9100-05
F2: Low Amp; 0679L9100-05
FB1: 120R; R_0805_2012Metric_Pad1.20x1.40mm_HandSolder
H1, H2, H3, H4: MountingHole; MountingHole_3.2mm_M3
J1: Conn_01x07_Socket; PinHeader_1x07_P2.54mm_Vertical
J3: Jack-DC; BarrelJack_CUI_PJ-063AH_Horizontal
J6, J7, J8: STX-3000; STX-3000_KYC
L1: 3.3uH; XGL6060
R1: 300k; R_0402_1005Metric_Pad0.72x0.64mm_HandSolder
R2, R3, R5: 100k; R_0402_1005Metric_Pad0.72x0.64mm_HandSolder
R4, R8, R12: 0R; R_0402_1005Metric_Pad0.72x0.64mm_HandSolder
R6: 10k; R_0603_1608Metric_Pad0.98x0.95mm_HandSolder
R7, R13: 1R; R_0603_1608Metric_Pad0.98x0.95mm_HandSolder
R9: 1.37k; R_0603_1608Metric_Pad0.98x0.95mm_HandSolder
R10: 3.01k; R_0603_1608Metric_Pad0.98x0.95mm_HandSolder
R11, R22: 11k; R_0402_1005Metric_Pad0.72x0.64mm_HandSolder
R14: 1R; R_0805_2012Metric_Pad1.20x1.40mm_HandSolder
R15: 24.9k; R_0603_1608Metric_Pad0.98x0.95mm_HandSolder
R16: 10k; R_0402_1005Metric_Pad0.72x0.64mm_HandSolder
R17, R19: 1k; R_0402_1005Metric_Pad0.72x0.64mm_HandSolder
R18: 47; R_0402_1005Metric_Pad0.72x0.64mm_HandSolder
R20: 790; R_0402_1005Metric_Pad0.72x0.64mm_HandSolder
R23: 200k; R_0402_1005Metric_Pad0.72x0.64mm_HandSolder
SW1: SW_SPDT_MSM; 100AWDP1T2B4M2QE
SW2: MCLR_SW; EVQ-P7A01P
TP1: SW; TestPoint_Loop_D2.50mm_Drill1.0mm
TP2: VDD; TestPoint_Loop_D2.50mm_Drill1.0mm
TP3: RC1; TestPoint_Loop_D2.50mm_Drill1.0mm
TP5: +48V; TestPoint_Loop_D2.50mm_Drill1.0mm
TP9: +5V; TestPoint_Loop_D2.50mm_Drill1.0mm
TP10: GND; TestPoint_Loop_D2.50mm_Drill1.0mm
U1: MIC28517T-E/PHA; VQFN32_6X6_3EP_PHA_MCH
U2: PIC18F56Q71-I/PT; TQFP48_PT_MCH
U3: SP485CN-L; NSOIC-8
U4: MSGEQ7; DIP-8_W7.62mm

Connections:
+5V: C2.1, C11.1, C12.1, C13.1, C14.1, C15.1, C17.2, C18.2, C19.2, C23.2, J1.2, L1.2, R6.2, R16.1, R19.2, R23.2, TP9.1, U2.7 (VDD), U2.30 (VDD), U3.2 (*RE), U3.3 (DE), U3.8 (VCC), U4.1 (VDD)
+48V: C6.1, F2.2, FB1.1, TP5.1
+48V_Hi_Amp: CON1.6, CON1.7, CON1.8, F1.2, R17.2
AGND: C1.2, C3.2, C5.2, C6.2, C8.2, C9.2, C11.2, C12.2, C13.2, C14.2, C15.2, C16.2, C17.1, C18.1, C19.1, C20.1, C22.2, C23.1, CON1.3, CON1.4, CON1.5, D1.1 (K), D2.1 (K), J1.3, J3.2, J6.1, J7.1, J8.1, R1.2, R4.1, R8.1, R9.1, R18.1, R20.1, SW1.2, SW2.2, TP10.1, U1.2 (PGND), U1.16 (PGND), U1.17 (PGND), U1.18 (PGND), U1.19 (PGND), U1.22 (PGND), U1.23 (EXTVDD), U1.29 (PGND), U1.33 (PGND), U1.EP19 (PGND), U2.1 (RC7), U2.2 (RD4), U2.3 (RD5), U2.4 (RD6), U2.5 (RD7), U2.6 (VSS), U2.8 (RB0), U2.9 (RB1), U2.12 (RF4), U2.13 (RF5), U2.14 (RF6), U2.15 (RF7), U2.17 (RB5), U2.23 (RA2), U2.24 (RA3), U2.25 (RA4), U2.26 (RA5), U2.28 (RE1), U2.29 (RE2), U2.31 (VSS), U2.32 (RA7), U2.33 (RA6), U2.36 (RF0), U2.37 (RF1), U2.38 (RF2), U2.39 (RF3), U2.40 (RC2), U2.41 (RC3), U2.42 (RD0), U2.43 (RD1), U2.44 (RD2), U2.45 (RD3), U2.46 (RC4), U2.47 (RC5), U2.48 (RC6), U3.1 (RO), U3.5 (GND), U4.2 (VSS)
AN_OUT: U2.27 (RE0), U4.3 (OUT)
AUDIO_IN: J6.2, J6.3, J7.2, J7.3, J8.2, J8.3, R11.1, R22.1
D+: CON1.1, U3.6 (A)
D-: CON1.2, U3.7 (B)
DMX OUT: J1.7, U2.34 (RC0), U3.4 (DI)
FB: C2.2, C10.2, R6.1, R9.2, U1.27 (FB)
ICSPCLK: J1.5, U2.18 (RB6/ICSPCLK)
ICSPDAT: J1.4, U2.19 (RB7/ICSPDAT)
ILIM: R10.2, U1.1 (ILIM)
MCLR: J1.1, R16.2, SW2.1, U2.20 (RE3/*MCLR/VPP)
MODE1: SW1.1, U2.21 (RA0)
MODE2: SW1.3, U2.22 (RA1)
unnamed: C4.1, R12.1
unnamed: C10.1, R15.1
unnamed: C16.1, R14.1
unnamed: C21.1, R11.2, R22.2
unnamed: D1.2 (A), R17.1, R18.2
unnamed: D2.2 (A), R19.1, R20.2
unnamed: F1.1, F2.1, J3.1
unnamed: R12.2, U1.4 (BST)
unnamed: R2.2, R4.2, U1.24 (EN)
unnamed: R1.1, R3.2, U1.25 (FREQ)
unnamed: R5.1, U1.32 (PG)
unnamed: R8.2, U1.28 (AGND)
unnamed: C5.1, R13.2, U1.21 (PVDD)
unnamed: C3.1, R7.2, U1.31 (SVIN)
unnamed: TP3.1, U2.35 (RC1)
unnamed: C20.2, R23.1, U4.8 (CKIN)
unnamed: C22.1, U4.6 (GND)
unnamed: C21.2, U4.5 (IN)
RESET: U2.10 (RB2), U4.7 (RESET)
STROBE: U2.11 (RB3), U4.4 (STROBE)
SW: C4.2, L1.1, R10.1, R14.2, R15.2, TP1.1, U1.3 (SW), U1.12 (SW), U1.13 (SW), U1.14 (SW), U1.15 (SW), U1.20 (SW), U1.EP12 (SW)
U1TX: J1.6, U2.16 (RB4)
VDD: C1.1, R5.2, R13.1, TP2.1, U1.26 (MODE), U1.30 (VDD)
VIN: C8.1, C9.1, FB1.2, R2.1, R3.1, R7.1, U1.5 (PVIN), U1.6 (PVIN), U1.7 (PVIN), U1.8 (PVIN), U1.9 (PVIN), U1.10 (PVIN), U1.11 (PVIN), U1.EP5 (PVIN)

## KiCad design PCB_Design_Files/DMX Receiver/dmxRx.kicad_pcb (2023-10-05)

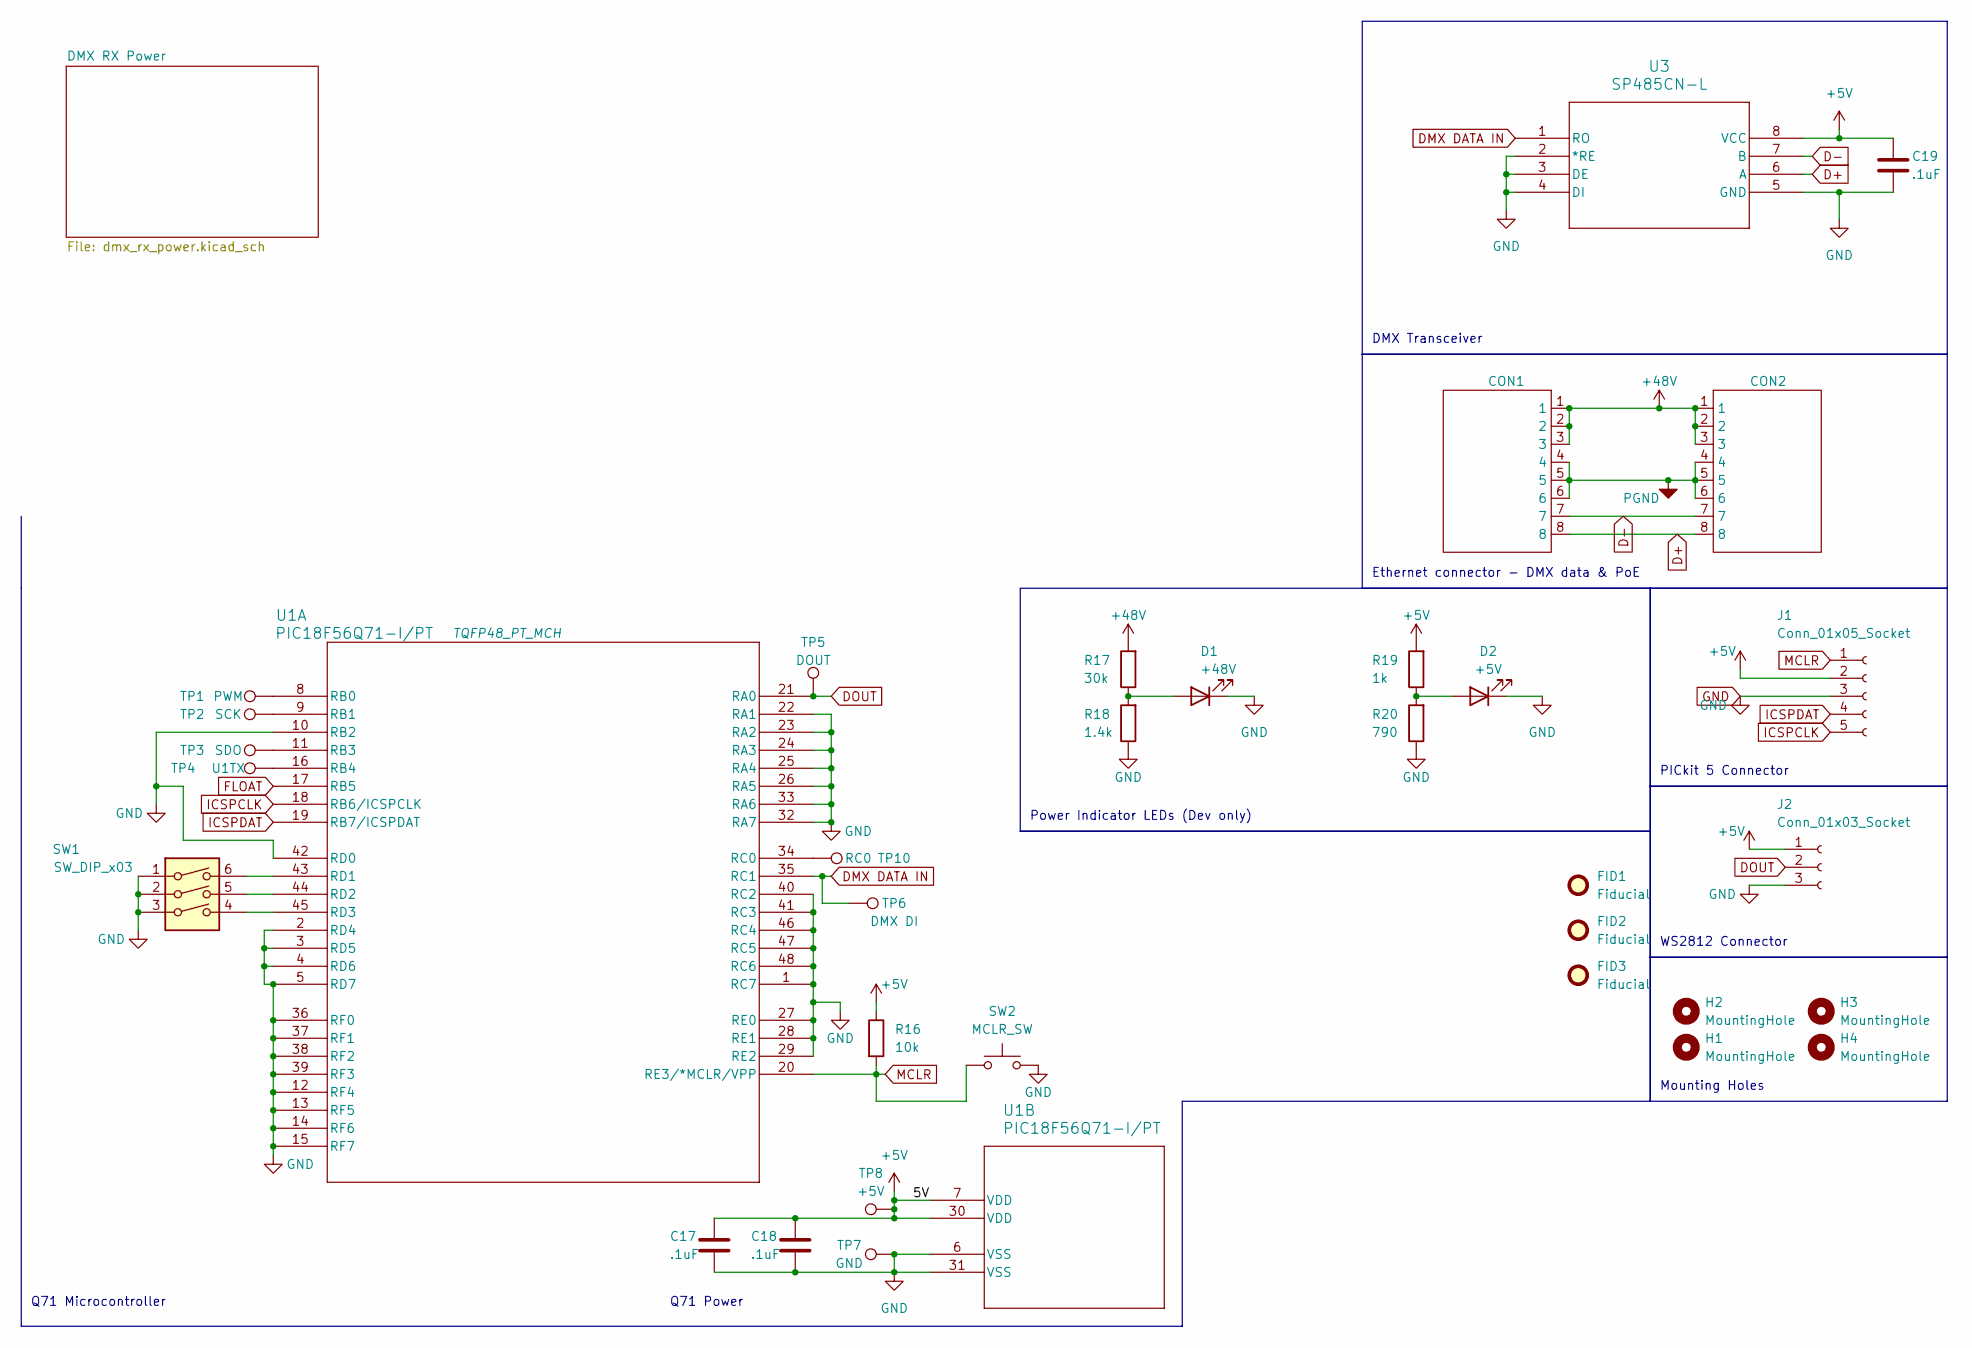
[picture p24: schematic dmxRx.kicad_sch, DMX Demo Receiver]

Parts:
C17, C18, C19: .1uF; C_0402_1005Metric_Pad0.74x0.62mm_HandSolder; Tolerance 10V
CON1, CON2: E5J88-00LJG2-L
D1: +48V; R_0201_0603Metric_Pad0.64x0.40mm_HandSolder
D2: +5V; R_0201_0603Metric_Pad0.64x0.40mm_HandSolder
FID1, FID2, FID3: Fiducial; Fiducial_1mm_Mask2mm
H1, H2, H3, H4: MountingHole; MountingHole_3.2mm_M3
J1: Conn_01x05_Socket; PinHeader_1x05_P2.54mm_Vertical
J2: Conn_01x03_Socket; PinHeader_1x03_P2.54mm_Vertical
R16: 10k; R_0402_1005Metric_Pad0.72x0.64mm_HandSolder
R17: 30k; R_0402_1005Metric_Pad0.72x0.64mm_HandSolder; Tolerance 5%
R18: 1.4k; R_0402_1005Metric_Pad0.72x0.64mm_HandSolder; Tolerance 1%
R19: 1k; R_0402_1005Metric_Pad0.72x0.64mm_HandSolder
R20: 790; R_0402_1005Metric_Pad0.72x0.64mm_HandSolder
SW1: SW_DIP_x03; DIP-6_W7.62mm
SW2: MCLR_SW; EVQ-P7A01P
TP1: PWM; TestPoint_Loop_D2.50mm_Drill1.0mm
TP2: SCK; TestPoint_Loop_D2.50mm_Drill1.0mm
TP3: SDO; TestPoint_Loop_D2.50mm_Drill1.0mm
TP4: U1TX; TestPoint_Loop_D2.50mm_Drill1.0mm
TP5: DOUT; TestPoint_Loop_D2.50mm_Drill1.0mm
TP6: DMX DI; TestPoint_Loop_D2.50mm_Drill1.0mm
TP7: GND; TestPoint_Loop_D2.50mm_Drill1.0mm
TP8: +5V; TestPoint_Loop_D2.50mm_Drill1.0mm
TP10: RC0; TestPoint_Loop_D2.50mm_Drill1.0mm
U1: PIC18F56Q71-I/PT; TQFP48_PT_MCH
U3: SP485CN-L; NSOIC-8

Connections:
+5V: C17.2, C18.2, C19.2, J1.2, J2.1, R16.1, R19.2, TP8.1, U1.7 (VDD), U1.30 (VDD), U3.8 (VCC); also elsewhere on the board
+48V: CON1.1, CON1.2, CON1.3, CON2.1, CON2.2, CON2.3, R17.2; also elsewhere on the board
D+: CON1.8, CON2.8, U3.6 (A)
D-: CON1.7, CON2.7, U3.7 (B)
DMX DATA IN: TP6.1, U1.35 (RC1), U3.1 (RO)
DOUT: J2.2, TP5.1, U1.21 (RA0)
FLOAT: U1.17 (RB5)
GND: C17.1, C18.1, C19.1, CON1.4, CON1.5, CON1.6, CON2.4, CON2.5, CON2.6, D1.1 (K), D2.1 (K), J1.3, J2.3, R18.1, R20.1, SW1.1, SW1.2, SW1.3, SW2.2, TP7.1, U1.1 (RC7), U1.2 (RD4), U1.3 (RD5), U1.4 (RD6), U1.5 (RD7), U1.6 (VSS), U1.10 (RB2), U1.12 (RF4), U1.13 (RF5), U1.14 (RF6), U1.15 (RF7), U1.22 (RA1), U1.23 (RA2), U1.24 (RA3), U1.25 (RA4), U1.26 (RA5), U1.27 (RE0), U1.28 (RE1), U1.29 (RE2), U1.31 (VSS), U1.32 (RA7), U1.33 (RA6), U1.36 (RF0), U1.37 (RF1), U1.38 (RF2), U1.39 (RF3), U1.40 (RC2), U1.41 (RC3), U1.42 (RD0), U1.46 (RC4), U1.47 (RC5), U1.48 (RC6), U3.2 (*RE), U3.3 (DE), U3.4 (DI), U3.5 (GND); also elsewhere on the board
ICSPCLK: J1.5, U1.18 (RB6/ICSPCLK)
ICSPDAT: J1.4, U1.19 (RB7/ICSPDAT)
MCLR: J1.1, R16.2, SW2.1, U1.20 (RE3/*MCLR/VPP)
unnamed: D1.2 (A), R17.1, R18.2
unnamed: D2.2 (A), R19.1, R20.2
unnamed: TP1.1, U1.8 (RB0)
unnamed: TP2.1, U1.9 (RB1)
unnamed: TP3.1, U1.11 (RB3)
unnamed: TP4.1, U1.16 (RB4)
unnamed: TP10.1, U1.34 (RC0)
unnamed: SW1.6, U1.43 (RD1)
unnamed: SW1.5, U1.44 (RD2)
unnamed: SW1.4, U1.45 (RD3)

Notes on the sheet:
DMX Transceiver
Ethernet connector - DMX data & PoE
WS2812 Connector
Q71 Power
PICkit 5 Connector
Power Indicator LEDs (Dev only)
Mounting Holes
Q71 Microcontroller

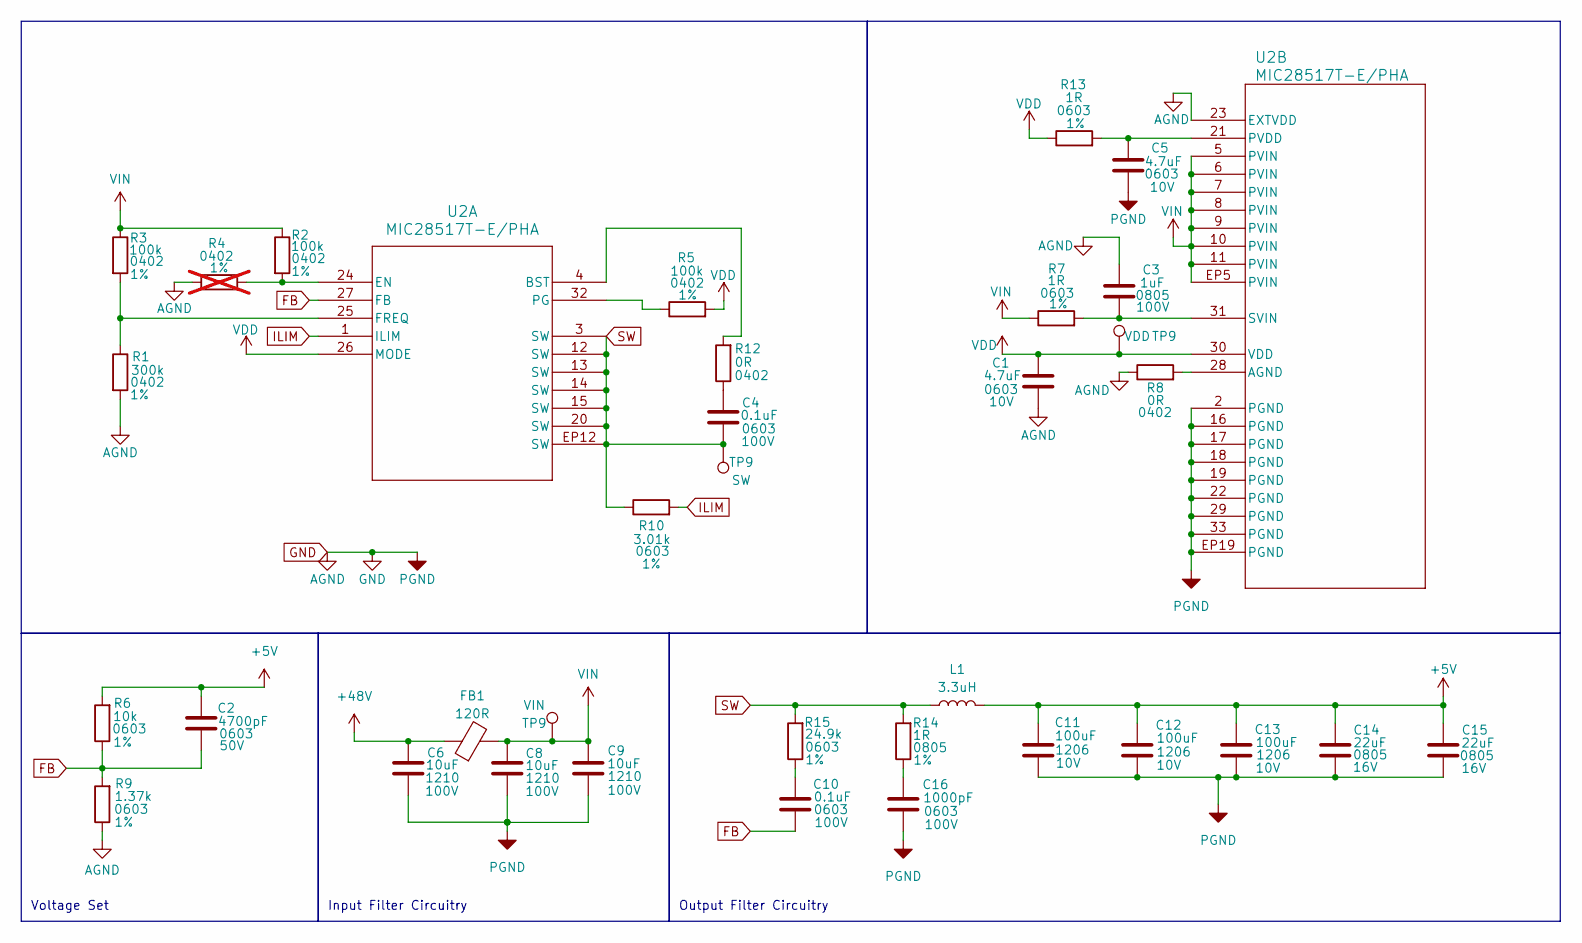
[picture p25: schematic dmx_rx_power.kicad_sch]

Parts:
C1, C5: 4.7uF; C_0603_1608Metric_Pad1.08x0.95mm_HandSolder; Tolerance N/A; Voltage 10V
C2: 4700pF; C_0603_1608Metric_Pad1.08x0.95mm_HandSolder; Tolerance N/A; Voltage 50V
C3: 1uF; C_0805_2012Metric_Pad1.18x1.45mm_HandSolder; Tolerance N/A; Voltage 100V
C4, C10: 0.1uF; C_0603_1608Metric_Pad1.08x0.95mm_HandSolder; Tolerance N/A; Voltage 100V
C6, C8, C9: 10uF; C_1210_3225Metric_Pad1.33x2.70mm_HandSolder; Tolerance N/A; Voltage 100V
C11, C12, C13: 100uF; C_1206_3216Metric_Pad1.33x1.80mm_HandSolder; Tolerance N/A; Voltage 10V
C14, C15: 22uF; C_0805_2012Metric_Pad1.18x1.45mm_HandSolder; Tolerance N/A; Voltage 16V
C16: 1000pF; C_0603_1608Metric_Pad1.08x0.95mm_HandSolder; Tolerance N/A; Voltage 100V
FB1: 120R; R_0805_2012Metric_Pad1.20x1.40mm_HandSolder; Tolerance N/A; Voltage N/A
L1: 3.3uH; XGL6060; Tolerance N/A; Voltage N/A
R1: 300k; R_0402_1005Metric_Pad0.72x0.64mm_HandSolder; Tolerance 1%; Voltage N/A
R2, R3, R5: 100k; R_0402_1005Metric_Pad0.72x0.64mm_HandSolder; Tolerance 1%; Voltage N/A
R4: 0R; R_0402_1005Metric_Pad0.72x0.64mm_HandSolder; Tolerance 1%; Voltage N/A; not fitted
R6: 10k; R_0603_1608Metric_Pad0.98x0.95mm_HandSolder; Tolerance 1%; Voltage N/A
R7, R13: 1R; R_0603_1608Metric_Pad0.98x0.95mm_HandSolder; Tolerance 1%; Voltage N/A
R8, R12: 0R; R_0402_1005Metric_Pad0.72x0.64mm_HandSolder; Voltage N/A; Tolerance N/A
R9: 1.37k; R_0603_1608Metric_Pad0.98x0.95mm_HandSolder; Voltage N/A; Tolerance 1%
R10: 3.01k; R_0603_1608Metric_Pad0.98x0.95mm_HandSolder; Voltage N/A; Tolerance 1%
R14: 1R; R_0805_2012Metric_Pad1.20x1.40mm_HandSolder; Tolerance 1%; Voltage N/A
R15: 24.9k; R_0603_1608Metric_Pad0.98x0.95mm_HandSolder; Voltage N/A; Tolerance 1%
TP9: VIN; TestPoint_Loop_D2.50mm_Drill1.0mm; Tolerance N/A; Voltage N/A
U2: MIC28517T-E/PHA; VQFN32_6X6_3EP_PHA_MCH; Tolerance N/A; Voltage N/A

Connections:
+5V: C2.1, C11.1, C12.1, C13.1, C14.1, C15.1, L1.2, R6.2; also elsewhere on the board
+48V: C6.1, FB1.1; also elsewhere on the board
FB: C2.2, C10.2, R6.1, R9.2, U2.27 (FB)
GND: C1.2, C3.2, C5.2, C6.2, C8.2, C9.2, C11.2, C12.2, C13.2, C14.2, C15.2, C16.2, R1.2, R4.1, R8.1, R9.1, U2.2 (PGND), U2.16 (PGND), U2.17 (PGND), U2.18 (PGND), U2.19 (PGND), U2.22 (PGND), U2.23 (EXTVDD), U2.29 (PGND), U2.33 (PGND), U2.EP19 (PGND); also elsewhere on the board
ILIM: R10.2, U2.1 (ILIM)
unnamed: C4.1, R12.1
unnamed: C10.1, R15.1
unnamed: C16.1, R14.1
unnamed: R12.2, U2.4 (BST)
unnamed: R2.2, R4.2, U2.24 (EN)
unnamed: R1.1, R3.2, U2.25 (FREQ)
unnamed: R5.1, U2.32 (PG)
unnamed: R8.2, U2.28 (AGND)
unnamed: C5.1, R13.2, U2.21 (PVDD)
unnamed: C3.1, R7.2, U2.31 (SVIN)

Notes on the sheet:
Voltage Set
Input Filter Circuitry
Output Filter Circuitry

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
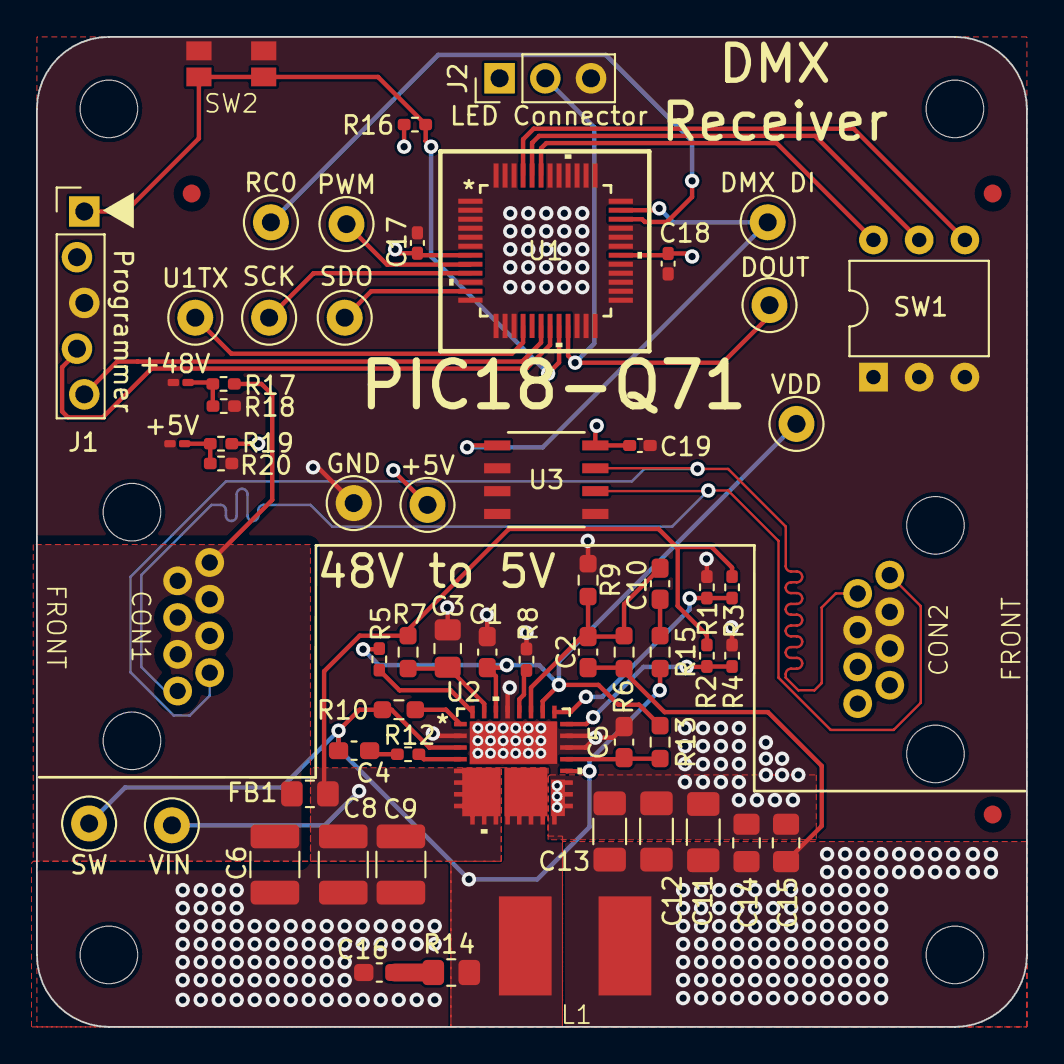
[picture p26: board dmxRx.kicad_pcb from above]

Board: 4 copper layers, 55.0 x 55.0 mm, 69 parts (0 on the bottom side), 35 nets.

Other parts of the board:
TP11: SW; TestPoint_Loop_D2.50mm_Drill1.0mm
TP12: VDD; TestPoint_Loop_D2.50mm_Drill1.0mm

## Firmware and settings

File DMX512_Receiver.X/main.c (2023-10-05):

/*
© [2023] Microchip Technology Inc. and its subsidiaries.

    Subject to your compliance with these terms, you may use Microchip 
    software and any derivatives exclusively with Microchip products. 
    You are responsible for complying with 3rd party license terms  
    applicable to your use of 3rd party software (including open source  
    software) that may accompany Microchip software. SOFTWARE IS ?AS IS.? 
    NO WARRANTIES, WHETHER EXPRESS, IMPLIED OR STATUTORY, APPLY TO THIS 
    SOFTWARE, INCLUDING ANY IMPLIED WARRANTIES OF NON-INFRINGEMENT,  
    MERCHANTABILITY, OR FITNESS FOR A PARTICULAR PURPOSE. IN NO EVENT 
    WILL MICROCHIP BE LIABLE FOR ANY INDIRECT, SPECIAL, PUNITIVE, 
    INCIDENTAL OR CONSEQUENTIAL LOSS, DAMAGE, COST OR EXPENSE OF ANY 
    KIND WHATSOEVER RELATED TO THE SOFTWARE, HOWEVER CAUSED, EVEN IF 
    MICROCHIP HAS BEEN ADVISED OF THE POSSIBILITY OR THE DAMAGES ARE 
    FORESEEABLE. TO THE FULLEST EXTENT ALLOWED BY LAW, MICROCHIP?S 
    TOTAL LIABILITY ON ALL CLAIMS RELATED TO THE SOFTWARE WILL NOT 
    EXCEED AMOUNT OF FEES, IF ANY, YOU PAID DIRECTLY TO MICROCHIP FOR 
    THIS SOFTWARE.
*/
#include "mcc_generated_files/system/system.h"
#include "dmx.h"
#include "dma.h"
#include "spi.h"
#include "tmr0.h"
#include "ws2812.h"

/*
 The receiver code flow can be broken down into 3 parts:
 * 1. DMX data is moved from the UART RX buffer to an array, rxData[], via DMA
 * 2. The main while loop converts the data in rxData[] into WS2812 G,R,B values stored in ledData[]
 * 3. DMA moves the WS2812 data from ledData[] into the SPI TX FIFO. By AND/ORing
 * a PWM & SPI signal in a CLC, any data sent out the SPI module is logically converted into the WS2812 protocol equivalent,
 * allowing the SPI peripheral to drive WS2812 leds
*/
int main(void)
{
//    setAllLeds(green);
    for(int i = 0; i < 11; i++){
        setLed(i, green);
    }
    for(int i = 11; i < 22; i++){
        setLed(i, yellow);
    }
    for(int i = 22; i < 25; i++){
        setLed(i, red);
    }    
    for(int i = 25; i < 34; i++){
        setLed(i, off);
    }    
    SYSTEM_Initialize(); // Initializes all the MCC generated functionality
    TMR0_Initialize(); // Generates a 60us interrupt for the WS2812 reset signal
    if(DMX_Initialize()){  // DMX initialize (bare metal code) checks if valid data selection is occurring
        setAllLeds(red);
    }
    SPI1_Initialize(); // Setup WS2812 communications
    DMA_Initialize(); // DMA initialize (bare metal code))
    
    INTERRUPT_GlobalInterruptHighEnable(); // Enable the Global High Interrupts 
    INTERRUPT_GlobalInterruptLowEnable(); // Enable the Global Low Interrupts 

    while(1){
        dmxToLed(); // Converts the DMX command data into WS2812 G,R,B equivalent
        //printf("%d,%d,%d,%d,%d,%d,%d\n",IO_RD1_GetValue(),IO_RD2_GetValue(),IO_RD3_GetValue(),IO_RD4_GetValue(),IO_RD5_GetValue(),IO_RD6_GetValue(),IO_RD7_GetValue());
//        printf("%d\n", getNodeNum());
    }
}

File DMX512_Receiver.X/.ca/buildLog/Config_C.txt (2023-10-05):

make -f nbproject/Makefile-Config_C.mk SUBPROJECTS= .clean-conf
make[1]: Entering directory 'C:/Users/C70636/Git Repo/dmx/DMX512_Receiver.X'
rm -f  -r .ca/build/Config_C/production
rm -f  -r .ca/dist/Config_C/production
make[1]: Leaving directory 'C:/Users/C70636/Git Repo/dmx/DMX512_Receiver.X'
[32mCLEAN SUCCESSFUL (total time: 204ms)[0m
make -f nbproject/Makefile-Config_C.mk SUBPROJECTS= .build-conf
make[1]: Entering directory 'C:/Users/C70636/Git Repo/dmx/DMX512_Receiver.X'
make  -f nbproject/Makefile-Config_C.mk .ca/dist/Config_C/production/DMX512_Receiver.X.production.hex
make[2]: Entering directory 'C:/Users/C70636/Git Repo/dmx/DMX512_Receiver.X'
"C:\Program Files\Microchip\xc8\v2.41\bin\xc8-cc.exe"  -mcpu=18F56Q71 -c   -mdfp="C:/Program Files/Microchip/MPLABX/v6.10/packs/Microchip/PIC18F-Q_DFP/1.17.379/xc8"  -fno-short-double -fno-short-float -memi=wordwrite -O3 -maddrqual=ignore -xassembler-with-cpp -mwarn=-3 -Wa,-a -DXPRJ_Config_C=Config_C  -msummary=-psect,-class,+mem,-hex,-file  -ginhx32 -Wl,--data-init -mno-keep-startup -mno-download -mdefault-config-bits   -std=c99 -gdwarf-3 -mstack=compiled:auto:auto:auto     -o .ca/build/Config_C/production/mcc_generated_files/clc/src/clc1.p1 mcc_generated_files/clc/src/clc1.c 
"C:\Program Files\Microchip\xc8\v2.41\bin\xc8-cc.exe"  -mcpu=18F56Q71 -c   -mdfp="C:/Program Files/Microchip/MPLABX/v6.10/packs/Microchip/PIC18F-Q_DFP/1.17.379/xc8"  -fno-short-double -fno-short-float -memi=wordwrite -O3 -maddrqual=ignore -xassembler-with-cpp -mwarn=-3 -Wa,-a -DXPRJ_Config_C=Config_C  -msummary=-psect,-class,+mem,-hex,-file  -ginhx32 -Wl,--data-init -mno-keep-startup -mno-download -mdefault-config-bits   -std=c99 -gdwarf-3 -mstack=compiled:auto:auto:auto     -o .ca/build/Config_C/production/mcc_generated_files/pwm/src/ccp1.p1 mcc_generated_files/pwm/src/ccp1.c 
"C:\Program Files\Microchip\xc8\v2.41\bin\xc8-cc.exe"  -mcpu=18F56Q71 -c   -mdfp="C:/Program Files/Microchip/MPLABX/v6.10/packs/Microchip/PIC18F-Q_DFP/1.17.379/xc8"  -fno-short-double -fno-short-float -memi=wordwrite -O3 -maddrqual=ignore -xassembler-with-cpp -mwarn=-3 -Wa,-a -DXPRJ_Config_C=Config_C  -msummary=-psect,-class,+mem,-hex,-file  -ginhx32 -Wl,--data-init -mno-keep-startup -mno-download -mdefault-config-bits   -std=c99 -gdwarf-3 -mstack=compiled:auto:auto:auto     -o .ca/build/Config_C/production/mcc_generated_files/spi/src/spi1.p1 mcc_generated_files/spi/src/spi1.c 
"C:\Program Files\Microchip\xc8\v2.41\bin\xc8-cc.exe"  -mcpu=18F56Q71 -c   -mdfp="C:/Program Files/Microchip/MPLABX/v6.10/packs/Microchip/PIC18F-Q_DFP/1.17.379/xc8"  -fno-short-double -fno-short-float -memi=wordwrite -O3 -maddrqual=ignore -xassembler-with-cpp -mwarn=-3 -Wa,-a -DXPRJ_Config_C=Config_C  -msummary=-psect,-class,+mem,-hex,-file  -ginhx32 -Wl,--data-init -mno-keep-startup -mno-download -mdefault-config-bits   -std=c99 -gdwarf-3 -mstack=compiled:auto:auto:auto     -o .ca/build/Config_C/production/mcc_generated_files/system/src/pins.p1 mcc_generated_files/system/src/pins.c 
"C:\Program Files\Microchip\xc8\v2.41\bin\xc8-cc.exe"  -mcpu=18F56Q71 -c   -mdfp="C:/Program Files/Microchip/MPLABX/v6.10/packs/Microchip/PIC18F-Q_DFP/1.17.379/xc8"  -fno-short-double -fno-short-float -memi=wordwrite -O3 -maddrqual=ignore -xassembler-with-cpp -mwarn=-3 -Wa,-a -DXPRJ_Config_C=Config_C  -msummary=-psect,-class,+mem,-hex,-file  -ginhx32 -Wl,--data-init -mno-keep-startup -mno-download -mdefault-config-bits   -std=c99 -gdwarf-3 -mstack=compiled:auto:auto:auto     -o .ca/build/Config_C/production/mcc_generated_files/system/src/config_bits.p1 mcc_generated_files/system/src/config_bits.c 
"C:\Program Files\Microchip\xc8\v2.41\bin\xc8-cc.exe"  -mcpu=18F56Q71 -c   -mdfp="C:/Program Files/Microchip/MPLABX/v6.10/packs/Microchip/PIC18F-Q_DFP/1.17.379/xc8"  -fno-short-double -fno-short-float -memi=wordwrite -O3 -maddrqual=ignore -xassembler-with-cpp -mwarn=-3 -Wa,-a -DXPRJ_Config_C=Config_C  -msummary=-psect,-class,+mem,-hex,-file  -ginhx32 -Wl,--data-init -mno-keep-startup -mno-download -mdefault-config-bits   -std=c99 -gdwarf-3 -mstack=compiled:auto:auto:auto     -o .ca/build/Config_C/production/mcc_generated_files/system/src/system.p1 mcc_generated_files/system/src/system.c 
"C:\Program Files\Microchip\xc8\v2.41\bin\xc8-cc.exe"  -mcpu=18F56Q71 -c   -mdfp="C:/Program Files/Microchip/MPLABX/v6.10/packs/Microchip/PIC18F-Q_DFP/1.17.379/xc8"  -fno-short-double -fno-short-float -memi=wordwrite -O3 -maddrqual=ignore -xassembler-with-cpp -mwarn=-3 -Wa,-a -DXPRJ_Config_C=Config_C  -msummary=-psect,-class,+mem,-hex,-file  -ginhx32 -Wl,--data-init -mno-keep-startup -mno-download -mdefault-config-bits   -std=c99 -gdwarf-3 -mstack=compiled:auto:auto:auto     -o .ca/build/Config_C/production/mcc_generated_files/system/src/interrupt.p1 mcc_generated_files/system/src/interrupt.c
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

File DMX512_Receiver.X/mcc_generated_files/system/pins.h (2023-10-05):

/**
 * Generated Pins header File
 * 
 * @file pins.h
 * 
 * @defgroup  pinsdriver Pins Driver
 * 
 * @brief This is generated driver header for pins. 
 *        This header file provides APIs for all pins selected in the GUI.
 *
 * @version Driver Version  3.1.0
*/

/*
© [2023] Microchip Technology Inc. and its subsidiaries.

    Subject to your compliance with these terms, you may use Microchip 
    software and any derivatives exclusively with Microchip products. 
    You are responsible for complying with 3rd party license terms  
    applicable to your use of 3rd party software (including open source  
    software) that may accompany Microchip software. SOFTWARE IS ?AS IS.? 
    NO WARRANTIES, WHETHER EXPRESS, IMPLIED OR STATUTORY, APPLY TO THIS 
    SOFTWARE, INCLUDING ANY IMPLIED WARRANTIES OF NON-INFRINGEMENT,  
    MERCHANTABILITY, OR FITNESS FOR A PARTICULAR PURPOSE. IN NO EVENT 
    WILL MICROCHIP BE LIABLE FOR ANY INDIRECT, SPECIAL, PUNITIVE, 
    INCIDENTAL OR CONSEQUENTIAL LOSS, DAMAGE, COST OR EXPENSE OF ANY 
    KIND WHATSOEVER RELATED TO THE SOFTWARE, HOWEVER CAUSED, EVEN IF 
    MICROCHIP HAS BEEN ADVISED OF THE POSSIBILITY OR THE DAMAGES ARE 
    FORESEEABLE. TO THE FULLEST EXTENT ALLOWED BY LAW, MICROCHIP?S 
    TOTAL LIABILITY ON ALL CLAIMS RELATED TO THE SOFTWARE WILL NOT 
    EXCEED AMOUNT OF FEES, IF ANY, YOU PAID DIRECTLY TO MICROCHIP FOR 
    THIS SOFTWARE.
*/

#ifndef PINS_H
#define PINS_H

#include <xc.h>

#define INPUT   1
#define OUTPUT  0

#define HIGH    1
#define LOW     0

#define ANALOG      1
#define DIGITAL     0

#define PULL_UP_ENABLED      1
#define PULL_UP_DISABLED     0

// get/set RA0 aliases
#define IO_RA0_TRIS                 TRISAbits.TRISA0
#define IO_RA0_LAT                  LATAbits.LATA0
#define IO_RA0_PORT                 PORTAbits.RA0
#define IO_RA0_WPU                  WPUAbits.WPUA0
#define IO_RA0_OD                   ODCONAbits.ODCA0
#define IO_RA0_ANS                  ANSELAbits.ANSELA0
#define IO_RA0_SetHigh()            do { LATAbits.LATA0 = 1; } while(0)
#define IO_RA0_SetLow()             do { LATAbits.LATA0 = 0; } while(0)
#define IO_RA0_Toggle()             do { LATAbits.LATA0 = ~LATAbits.LATA0; } while(0)
#define IO_RA0_GetValue()           PORTAbits.RA0
#define IO_RA0_SetDigitalInput()    do { TRISAbits.TRISA0 = 1; } while(0)
#define IO_RA0_SetDigitalOutput()   do { TRISAbits.TRISA0 = 0; } while(0)
#define IO_RA0_SetPullup()          do { WPUAbits.WPUA0 = 1; } while(0)
#define IO_RA0_ResetPullup()        do { WPUAbits.WPUA0 = 0; } while(0)
#define IO_RA0_SetPushPull()        do { ODCONAbits.ODCA0 = 0; } while(0)
#define IO_RA0_SetOpenDrain()       do { ODCONAbits.ODCA0 = 1; } while(0)
#define IO_RA0_SetAnalogMode()      do { ANSELAbits.ANSELA0 = 1; } while(0)
#define IO_RA0_SetDigitalMode()     do { ANSELAbits.ANSELA0 = 0; } while(0)

// get/set RB0 aliases
#define IO_RB0_TRIS                 TRISBbits.TRISB0
#define IO_RB0_LAT                  LATBbits.LATB0
#define IO_RB0_PORT                 PORTBbits.RB0
#define IO_RB0_WPU                  WPUBbits.WPUB0
#define IO_RB0_OD                   ODCONBbits.ODCB0
#define IO_RB0_ANS                  ANSELBbits.ANSELB0
#define IO_RB0_SetHigh()            do { LATBbits.LATB0 = 1; } while(0)
#define IO_RB0_SetLow()             do { LATBbits.LATB0 = 0; } while(0)
#define IO_RB0_Toggle()             do { LATBbits.LATB0 = ~LATBbits.LATB0; } while(0)
#define IO_RB0_GetValue()           PORTBbits.RB0
#define IO_RB0_SetDigitalInput()    do { TRISBbits.TRISB0 = 1; } while(0)
#define IO_RB0_SetDigitalOutput()   do { TRISBbits.TRISB0 = 0; } while(0)
#define IO_RB0_SetPullup()          do { WPUBbits.WPUB0 = 1; } while(0)
#define IO_RB0_ResetPullup()        do { WPUBbits.WPUB0 = 0; } while(0)
#define IO_RB0_SetPushPull()        do { ODCONBbits.ODCB0 = 0; } while(0)
#define IO_RB0_SetOpenDrain()       do { ODCONBbits.ODCB0 = 1; } while(0)
#define IO_RB0_SetAnalogMode()      do { ANSELBbits.ANSELB0 = 1; } while(0)
#define IO_RB0_SetDigitalMode()     do { ANSELBbits.ANSELB0 = 0; } while(0)

// get/set RB2 aliases
#define IO_RB2_TRIS                 TRISBbits.TRISB2
#define IO_RB2_LAT                  LATBbits.LATB2
#define IO_RB2_PORT                 PORTBbits.RB2
#define IO_RB2_WPU                  WPUBbits.WPUB2
#define IO_RB2_OD                   ODCONBbits.ODCB2
#define IO_RB2_ANS                  ANSELBbits.ANSELB2
#define IO_RB2_SetHigh()            do { LATBbits.LATB2 = 1; } while(0)
#define IO_RB2_SetLow()             do { LATBbits.LATB2 = 0; } while(0)
#define IO_RB2_Toggle()             do { LATBbits.LATB2 = ~LATBbits.LATB2; } while(0)
#define IO_RB2_GetValue()           PORTBbits.RB2
#define IO_RB2_SetDigitalInput()    do { TRISBbits.TRISB2 = 1; } while(0)
#define IO_RB2_SetDigitalOutput()   do { TRISBbits.TRISB2 = 0; } while(0)
#define IO_RB2_SetPullup()          do { WPUBbits.WPUB2 = 1; } while(0)
#define IO_RB2_ResetPullup()        do { WPUBbits.WPUB2 = 0; } while(0)
#define IO_RB2_SetPushPull()        do { ODCONBbits.ODCB2 = 0; } while(0)
#define IO_RB2_SetOpenDrain()       do { ODCONBbits.ODCB2 = 1; } while(0)
#define IO_RB2_SetAnalogMode()      do { ANSELBbits.ANSELB2 = 1; } while(0)
#define IO_RB2_SetDigitalMode()     do { ANSELBbits.ANSELB2 = 0; } while(0)

// get/set RB4 aliases
#define IO_RB4_TRIS                 TRISBbits.TRISB4
#define IO_RB4_LAT                  LATBbits.LATB4
#define IO_RB4_PORT                 PORTBbits.RB4
#define IO_RB4_WPU                  WPUBbits.WPUB4
#define IO_RB4_OD                   ODCONBbits.ODCB4
#define IO_RB4_ANS                  ANSELBbits.ANSELB4
#define IO_RB4_SetHigh()            do { LATBbits.LATB4 = 1; } while(0)
#define IO_RB4_SetLow()             do { LATBbits.LATB4 = 0; } while(0)
#define IO_RB4_Toggle()             do { LATBbits.LATB4 = ~LATBbits.LATB4; } while(0)
#define IO_RB4_GetValue()           PORTBbits.RB4
#define IO_RB4_SetDigitalInput()    do { TRISBbits.TRISB4 = 1; } while(0)
#define IO_RB4_SetDigitalOutput()   do { TRISBbits.TRISB4 = 0; } while(0)
#define IO_RB4_SetPullup()          do { WPUBbits.WPUB4 = 1; } while(0)
#define IO_RB4_ResetPullup()        do { WPUBbits.WPUB4 = 0; } while(0)
#define IO_RB4_SetPushPull()        do { ODCONBbits.ODCB4 = 0; } while(0)
#define IO_RB4_SetOpenDrain()       do { ODCONBbits.ODCB4 = 1; } while(0)
#define IO_RB4_SetAnalogMode()      do { ANSELBbits.ANSELB4 = 1; } while(0)
#define IO_RB4_SetDigitalMode()     do { ANSELBbits.ANSELB4 = 0; } while(0)
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

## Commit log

2023-10-05 MPAE-16207: Initial commit
    [Config_A.txt, Config_B.txt, Config_C.txt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]
2023-10-09 MPAE-16207: Updated readme, rename folders
    [DmxRxCleaned (version 1).xlsb.csv, DmxRxCleaned.csv, DmxTxCleaned.csv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]
